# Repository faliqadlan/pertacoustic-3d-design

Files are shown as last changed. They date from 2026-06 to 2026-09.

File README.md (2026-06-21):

# Pertacoustic Study: Spectral Noise Logging (SNL) Well Diagnostics

This repository contains the software configuration, design targets, and research artifacts for the **Pertacoustic Study** (Studi Pertacoustic untuk Mengatasi Permasalahan Air), a joint research and development project conducted in collaboration with **Laboratorium Geofisika FMIPA Universitas Gadjah Mada (UGM)** and **PT Pertamina Hulu Energi (PHE) Upstream Innovation**.

---

## Project Overview
The project focuses on developing hardware and software components for high-sensitivity, high-resolution **Spectral Noise Logging (SNL)** using downhole hydrophones. SNL is a passive acoustic diagnostic methodology used to detect and characterize:
- Tubing and casing leaks
- Behind-casing fluid migration (cement channeling)
- Reservoir fluid inflow and production profiles
- Cross-flow behind single or multiple concentric barriers

---

## Repository Structure
*   `2604.05547v1.pdf`: Research reference on closed-loop CAD-CAE agentic optimization (COSMO-Agent).
*   `260619_PERTACOUSTIC_BIWEEKLY_2.pdf`: Biweekly progress report II (UGM & Pertamina Hulu Energi).
*   `FIND-specification-flyer.pdf`: North Side Tools FIND (Flow Identifying Noise Detector) specifications.
*   `commercial_snl_tools.md`: Comparative study of major commercial downhole SNL tools (GOWell SNT, TGT Chorus, Schlumberger HFND, etc.).
*   `pertacoustic_tool_targets.md`: Wellbore environmental operating specifications tailored for PHE oil wells.
*   `downhole_tool_components.md`: Auxiliary components list, specifications, pricing, and system-level budgets.
*   `SESSION_LOG.md`: Session logs and progress summary.

---

## Technical Specifications Target (PHE Oil Wells)
- **Temperature Limits**: 150°C BHT max (supporting standard reservoirs and steamflood EOR like Duri field).
- **Hydrostatic Pressure**: 10,000 PSI max (engineered for standard development and exploratory oil wells).
- **Depth Limit**: 3,500 meters.
- **Fluid Compatibility**: Heavy crude oil (17° to 22° API).
- **Sour Service Certification**: 6% to 25% H2S, 10% CO2.

---

## Persistent Session Memory (Antigravity 2.0)

To prevent the Antigravity agent from starting discussions from scratch when you open a new conversation or switch machines, follow these memory-preservation guidelines:

### 1. Maintain `SESSION_LOG.md` (Episodic Memory)
*   **How it works**: Antigravity automatically scans and reads all markdown files in the workspace at initialization.
*   **Action**: Ensure that `SESSION_LOG.md` is updated at the end of each session. The agent will read this log in any new conversation to immediately recall previous discussions, decisions, and files without requiring you to re-explain.

### 2. Define Workspace Rules in `.agents/AGENTS.md` (Procedural Memory)
*   **How it works**: Workspace-scoped agent rules are automatically loaded into the agent's system instructions at startup.
*   **Action**: Add custom rules in `.agents/AGENTS.md` to define design decisions (e.g., *"We are building Option C (Hybrid Premium AS-1 + Titanium Casing) at ~$4,353 USD"*). This locks the current architecture choice into the agent's behavior.

### 3. Synchronize via GitHub (Cross-Laptop Sync)
*   **How it works**: Git acts as the shared long-term memory across different computers.
*   **Action**: 
    1.  At the end of a session, run: `git add . && git commit -m "sync memory" && git push`
    2.  When opening a new conversation or using a different laptop, run: `git pull` before launching the agent.
    3.  This restores the exact workspace files, agent rules, custom skills, and logs.

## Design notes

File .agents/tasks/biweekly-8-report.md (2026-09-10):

---
title: PertAcoustic Biweekly 8 Reporting Contract
document_id: AGENT-TASK-BIWEEKLY-8-REPORT
version: 1.1
status: Validated/Published
language: en-US
last_updated: 2026-09-10
scope:
  - PertAcoustic Biweekly 8 report generation
  - accepted compact-casing evidence synthesis
  - reporting traceability and evidence labeling
  - native Google Docs human-facing deliverable
  - reporting-only repository source artifact maintenance
authority_note: This task authorizes a reporting and traceability deliverable only. It does not redefine, broaden, amend, supersede, or retroactively reinterpret the compact-casing engineering contract or accepted engineering evidence.
---

# Executable Task

This file defines the bounded delivery contract for remediating the PertAcoustic Biweekly 8 report in a later Executor run.

The report is a communication and traceability artifact derived from accepted repository evidence. The repository Markdown remains the traceability/source artifact; the primary human-facing deliverable is a native Google Doc. Neither artifact is the engineering source of truth.

## Task identity

**Task title:**  
PertAcoustic Biweekly 8 Evidence-Based Progress Report

**Task path:**  
`.agents/tasks/biweekly-8-report.md`

**Task contract state:**  
Validated/Published

The task file is the executable delivery contract.

Execution and review lifecycle states such as `In Execution`, `Review Required`, `Remediation Required`, and `Accepted` SHOULD normally be tracked by orchestration, review records, repository metadata, or another mechanism that preserves the exact governing task revision.

A lifecycle-status update MUST NOT silently replace the immutable task revision that governed an execution attempt.

When remediation materially changes this executable contract, edit this same stable task path, return it to Draft as needed, and republish it as a new immutable governing task revision before renewed execution.

**Delivery objective / Work Package / MVP:**  
PertAcoustic reporting work package: Biweekly 8 accepted-evidence report

**Owner / designated planning authority:**  
PertAcoustic Research Collaboration / Planner-Reviewer reporting authority

## Delivery context

Biweekly 8 must summarize accepted PertAcoustic engineering progress at the current reporting cutoff:

```text
main@667ccd59cf6657a75dfe3cc2b4c67488737ef028
```

The principal engineering work being reported is governed by:

```text
.agents/tasks/compact-downhole-casing-redesign.md @ ad24d9146815f88368d8f6b1d635831d57aed13d
```

That engineering task recorded implementation baseline:

```text
b33e1622b04ec5e723c634573dbfa93aaa065576
```

The current report implementation requiring remediation is:

```text
29a602029cf55a0b036887d776440447325bd864
```

That implementation created the repository source artifact:

```text
results/biweekly-8/biweekly-8.md
```

The future remediated report must explain, with traceable evidence:

1. what the engineering state was before the compact-casing redesign;
2. what engineering work was completed;
3. what evidence was produced;
4. what changed from the previous accepted baseline;
5. what the current preliminary engineering configuration is;
6. which results are VERIFIED, DERIVED SCREENING, ASSUMED SCREENING, HISTORICAL, PROVISIONAL, or UNRESOLVED;
7. what remains unresolved; and
8. what engineering work should happen next.

The report must be suitable for PertAcoustic project members, academic supervisors, engineering collaborators, and project decision-makers. Technical clarity and traceability are more important than presentation decoration.

The primary human-facing deliverable MUST be a native Google Doc titled:

```text
3d-design-biweekly-8
```

The Google Doc MUST be created directly in the specified PertAcoustic Google Drive folder:

```text
https://drive.google.com/drive/folders/14V4rGX0lwHmwCNOGn8BQYE-0R6DH-Fy9
```

The existing Biweekly 5 Google Doc is a formatting and editorial template only:

```text
https://docs.google.com/document/d/1hAxKtHvkiHflduqY9msiPGFDHWHsi38WFNxwXvtDBFk/edit
```

The Biweekly 5 Google Doc and repository Biweekly 5 artifacts are historical engineering evidence. They MUST NOT be cited or treated as current engineering authority. If the Google Doc is copied as a native formatting template, copied historical content MUST be replaced or clearly relabeled as historical. Biweekly 5 may constrain only the visual/editorial form of the Biweekly 8 Google Doc.

The repository/project evidence inspected for task publication does not establish a reliable Biweekly 6 / Biweekly 7 reporting-period chain. The future report MUST NOT invent reporting-period dates or a Biweekly 7 repository artifact. If authoritative dates remain unavailable, record the dates as unresolved and make the evidence cutoff explicit.

## Baseline and task revision

**Implementation baseline:**  
`29a602029cf55a0b036887d776440447325bd864`

**Task revision:**  
Resolved by the immutable Git commit that publishes this task file. The preferred identity is:

```text
.agents/tasks/biweekly-8-report.md @ <full Git commit SHA containing this task content>
```

The task body does not need to embed the commit SHA that contains itself. The Executor MUST use the exact immutable task revision supplied by the Planner/Reviewer handoff or Git history before starting report generation.

The implementation baseline and governing task revision are separate references. The implementation baseline is the current report implementation requiring remediation. The accepted engineering reporting cutoff remains `667ccd59cf6657a75dfe3cc2b4c67488737ef028`.

Do not change the implementation baseline silently during execution. If `origin/main` or the accepted reporting cutoff has moved, stop and return to Planner/Reviewer for reporting-cutoff review before remediating Biweekly 8.

## Objective

Remediate the existing coherent, evidence-based PertAcoustic Biweekly 8 report from accepted repository evidence by keeping `results/biweekly-8/biweekly-8.md` as the repository traceability/source artifact and creating a native Google Docs primary human-facing deliverable in the specified PertAcoustic Drive folder.

The report MUST synthesize accepted engineering evidence without making new engineering design decisions, changing source-of-truth engineering artifacts, or overstating preliminary screening as qualification.

## Authoritative inputs

### Governing authority

- Repository delivery governance:
  - `AGENTS.md`
  - `.agents/AGENTS.md`
  - `.agents/software-workflow.md`
  - `.agents/context/project.md`
- This reporting task:
  - `.agents/tasks/biweekly-8-report.md @ <published immutable task revision>`
- Governing compact-casing engineering task:
  - `.agents/tasks/compact-downhole-casing-redesign.md @ ad24d9146815f88368d8f6b1d635831d57aed13d`
- Accepted reporting cutoff:
  - `main@667ccd59cf6657a75dfe3cc2b4c67488737ef028`
- Previous governing reporting task revision:
  - `.agents/tasks/biweekly-8-report.md @ c1d8d7c00d6fe3b3055bdabebb604f4e49bb86cb`
- Current report implementation requiring remediation:
  - `29a602029cf55a0b036887d776440447325bd864`
- Biweekly 8 Google Doc target:
  - Title: `3d-design-biweekly-8`
  - Folder: `https://drive.google.com/drive/folders/14V4rGX0lwHmwCNOGn8BQYE-0R6DH-Fy9`
- Formatting/editorial template only:
  - Biweekly 5 Google Doc: `https://docs.google.com/document/d/1hAxKtHvkiHflduqY9msiPGFDHWHsi38WFNxwXvtDBFk/edit`

### Primary repository evidence

Prioritize evidence in this order:

1. Current accepted repository implementation and generated results at the reporting cutoff.
2. The exact governing engineering task revision.
3. Actual executed test, simulation, CAD, and generated evidence.
4. Formal project decisions represented in repository authority/context.
5. Manufacturer, supplier, standard, or paper evidence already properly traced by the accepted engineering work.
6. Engineering measurements.
7. Historical Biweekly reports.
8. Informal discussion or context only when appropriately labeled.

Important evidence surfaces include:

- `results/compact-casing/compact_casing_redesign_report.md`
- `results/compact-casing/compact_casing_id_od_envelope.csv`
- `results/compact-casing/compact_casing_trade_study.csv`
- `results/compact-casing/figures/`
- `cosmo/compact_casing.py`
- `tests/test_compact_casing.py`
- `results/biweekly-5/biweekly-5.md`
- `results/biweekly-5/figures/`
- `results/biweekly-5/cad/`
- `results/biweekly-5/summary.json`
- `results/biweekly-5/thermal_results.csv`
- `results/biweekly-5/structural_fea_results.csv`
- `results/biweekly-5/mesh_convergence.csv`
- `results/biweekly-5/input_spec.json`
- `.agents/context/biweekly-5/`
- `results/biweekly-8/biweekly-8.md`

Historical Biweekly 5 artifacts must remain unchanged.

The Biweekly 5 Google Doc and repository Biweekly 5 artifacts are HISTORICAL engineering evidence. They may be used for formatting/editorial style and previous-baseline comparison only. They MUST NOT be treated as current engineering authority.

### Requirement traceability

- `REQ-RPT8-001` (Evidence-bound report) -> This task, repository governance, and reporting cutoff: Biweekly 8 must synthesize accepted evidence without inventing unsupported progress.
- `REQ-RPT8-002` (Current configuration reconciliation) -> Accepted compact-casing evidence: the report must reconcile preliminary dimensions, materials, architecture, and status labels against repository evidence before publication.
- `REQ-RPT8-003` (Strict thermal semantics) -> Accepted compact-casing evidence and task constraints: shell-coupled lower-bound thermal results must not be relabeled as electronics temperature.
- `REQ-RPT8-004` (Strict structural semantics) -> Accepted compact-casing evidence and unresolved pressure authority: structural screening must remain conditional and must not be presented as pressure qualification.
- `REQ-RPT8-005` (Historical preservation) -> Repository context and historical reporting evidence: Biweekly 5 artifacts must remain unchanged and historical facts must be labeled historical.
- `REQ-RPT8-006` (Traceable reporting package) -> Repository reporting convention and human requirement change: `results/biweekly-8/biweekly-8.md` remains the repository traceability/source artifact, while the native Google Doc is the primary human-facing deliverable.
- `REQ-RPT8-007` (Native Google Docs deliverable) -> Human requirement change: Biweekly 8 must be created as a native Google Doc titled `3d-design-biweekly-8` directly in the specified PertAcoustic Google Drive folder.
- `REQ-RPT8-008` (Biweekly 5 style template boundary) -> Human requirement change: the Biweekly 8 Google Doc must closely match the visual/editorial structure of the Biweekly 5 Google Doc while treating Biweekly 5 only as historical evidence and formatting/editorial template material.

Do not use existing implementation as retroactive justification for missing authority.

## Scope

### In scope

- Synthesize accepted engineering evidence into a Biweekly 8 report.
- Preserve and, if needed, update the repository source artifact under:

```text
results/biweekly-8/
  biweekly-8.md
  figures/        if justified
  supporting generated evidence only when required
```

- Create a native Google Doc titled `3d-design-biweekly-8` directly in:

```text
https://drive.google.com/drive/folders/14V4rGX0lwHmwCNOGn8BQYE-0R6DH-Fy9
```

- Use the Biweekly 5 Google Doc only as a formatting/editorial template.
- Write the primary Google Doc in Indonesian.
- Match the Biweekly 5 Google Doc style closely enough to preserve report readability and audience expectations, including report-style title, period/date/status block, concise disclaimer, numbered engineering sections, explanatory prose, native Google Docs tables, inline engineering figures, figure captions, references section, typography, heading hierarchy, and page layout.
- Select relevant accepted engineering figures when useful.
- Create reporting-only explanatory tables or figures when justified by traceability and generated from accepted evidence.
- Create evidence and traceability tables where useful.
- Record the final Google Doc identity, URL, and folder placement in the Executor's evidence and, if appropriate, in `results/biweekly-8/biweekly-8.md` without turning the Google Doc into engineering authority.
- Document unresolved engineering gaps.
- Document next engineering work.
- Verify report consistency, dimensions, units, claims, evidence links, and figure captions.

### Out of scope

- Creating `results/biweekly-8/` or `biweekly-8.md` before this task is executed in a future reporting slice.
- Changing the current engineering design.
- Choosing a different OD merely for reporting.
- Changing casing wall thickness.
- Changing material selection.
- Introducing a new carrier material.
- Modifying thermal physics.
- Changing structural models.
- Changing pressure assumptions.
- Changing HTI geometry.
- Inventing actual electronics dimensions.
- Inventing measured power dissipation.
- Fabricating prototype results.
- Claiming field qualification, pressure qualification, manufacturing readiness, or downhole qualification.
- Modifying, renaming, overwriting, or regenerating historical Biweekly 5 evidence.
- Modifying the Biweekly 5 Google Doc.
- Modifying `cosmo/compact_casing.py`, compact-casing result artifacts, tests, or other engineering source-of-truth data to make the report easier to write.
- Creating a PDF, slide deck, or alternative publication artifact unless separately authorized.
- Treating the Google Doc, Biweekly 5 Google Doc, or the Markdown report as engineering source-of-truth authority.

### Preserved behavior

- Historical reporting directories remain unchanged, especially `results/biweekly-5/`.
- The Biweekly 5 Google Doc remains unchanged.
- Compact-casing engineering source and accepted generated evidence remain unchanged.
- Repository governance and task contract semantics remain unchanged.
- `results/biweekly-8/biweekly-8.md` remains the repository traceability/source artifact.
- Preliminary engineering results remain clearly preliminary.
- Assumptions, historical values, and unresolved items remain visible.

If report preparation exposes a genuine engineering inconsistency, record it as a reporting blocker or finding rather than silently fixing engineering source-of-truth data inside this reporting task.

## Current engineering baseline to preserve

Before publication, the future report MUST reconcile these current accepted preliminary values against repository evidence:

- Pressure shell: Inconel 718.
- Preferred casing OD: 44.45 mm / 1.75 in.
- Maximum screening OD: 57.15 mm / 2.25 in.
- Preliminary wall: 3.50 mm.
- Resulting shell bore: 37.45 mm.
- Project internal-diameter direction: ID > 30 mm.
- Critical interpretation: 30 mm is a lower bound, not the target internal diameter.
- Current electronics screening requirement: approximately 34.93 mm circular packaging envelope.
- Current preliminary diametral packaging margin: approximately 2.52 mm.
- Current architecture:
  - Inconel 718 metallic pressure shell.
  - Discrete/conformal polymer electronics carrier.
  - Electronics inside the carrier.
  - No aerogel baseline.
- Carrier hierarchy:
  - PA66-GF30: PRIMARY NYLON PROTOTYPE / VALIDATION CANDIDATE.
  - PEEK: ENGINEERING BENCHMARK / REFERENCE.
  - PPA: HIGHER-PERFORMANCE POLYAMIDE ALTERNATIVE / SECONDARY VALIDATION CANDIDATE.

The report MUST NOT call:

- PA66 downhole-qualified;
- the polymer carrier a pressure boundary;
- the current casing pressure-qualified;
- the current design manufacturing-ready;
- the design field-qualified.

## Reporting content requirements

The Google Doc MUST be written in Indonesian and use explanatory engineering prose rather than audit-oriented prose. It MUST include, at minimum:

1. Ringkasan Kemajuan.
2. Periode, status, dan batas bukti.
3. Pekerjaan yang selesai pada periode pelaporan.
4. Konfigurasi teknik saat ini.
5. Analisis teknik, covering these topics where supported:
   - mechanical packaging;
   - ID/OD envelope;
   - material/carrier selection;
   - structural screening;
   - thermal screening;
   - electronics packaging;
   - HTI/acoustic interface.
6. Perbandingan dengan baseline sebelumnya, explicitly explaining the transition from the earlier large casing / aerogel-oriented concept toward the compact architecture.
7. Verifikasi dan bukti, including the exact repository revision and generated evidence used.
8. Keputusan teknik saat ini.
9. Hal yang belum terselesaikan / risiko.
10. Pekerjaan teknik berikutnya.
11. Referensi.
12. Evidence / traceability table where useful.

The Google Doc MUST closely match the Biweekly 5 document's visual and editorial pattern:

- Indonesian language.
- Report-style title.
- Period/date/status block near the top.
- Concise disclaimer that the report is not a manufacturing drawing, pressure qualification, field qualification, or new engineering source of truth.
- Numbered engineering sections.
- Explanatory prose rather than audit-oriented prose.
- Native Google Docs tables, not pasted Markdown table text or screenshots of tables.
- Engineering figures embedded inline from accepted evidence when useful.
- Figure captions placed next to the corresponding figures.
- References section.
- Approximately the same typography, heading hierarchy, page layout, and overall readability as the Biweekly 5 Google Doc.

`results/biweekly-8/biweekly-8.md` MUST remain an English or repository-conventional traceability/source artifact unless the Executor has a clearly bounded reason to translate it. The Google Doc is the Indonesian human-facing deliverable.

Assess and include these items only when supported by reporting-cutoff evidence:

- compact-casing redesign;
- 1.75 in / 44.45 mm OD recommendation;
- 3.50 mm preliminary Inconel wall;
- 37.45 mm bore;
- 30 mm ID as lower bound rather than target;
- current approximately 34.93 mm electronics screening requirement;
- approximately 2.52 mm packaging margin;
- removal of aerogel from the current baseline;
- PA66-GF30 first-prototype direction;
- PEEK benchmark/reference role;
- PPA secondary-candidate role;
- structural-screening results;
- unresolved authoritative pressure;
- current shell thermal-screening results;
- limitations of the present thermal model;
- actual electronics dimensional measurement requirement;
- actual electronics power requirement;
- planned PA66 physical validation;
- next thermal-development step;
- unresolved HTI supplier-controlled thread/seal/interface geometry.

Do not add unsupported engineering progress merely to make Biweekly 8 appear more substantial.

## Thermal semantics

The report MUST use strict thermal wording.

The current 70 C model may support discussion of:

- shell response;
- inner-shell temperature;
- shell-coupled lower-bound behavior;
- present thermal-screening limitations.

It MUST NOT be presented as directly establishing:

- PCB temperature;
- electronics cavity temperature;
- STM32 junction temperature;
- PCM1808 junction temperature;
- complete electronics temperature;
- electronics qualification.

The current result is:

```text
IDEAL SHELL-COUPLED LOWER-BOUND TEMPERATURE (INNER SHELL SURFACE)
```

Do not relabel it as "electronics temperature".

The report MUST explicitly state that stronger thermal work requires:

```text
environment
-> Inconel shell
-> shell/carrier contact
-> polymer carrier
-> PCB/contact
-> electronics heat sources
```

with measured or justified thermal resistances and actual electronics power.

## Structural semantics

Structural conclusions MUST remain:

```text
CONDITIONAL - DESIGN PRESSURE UNRESOLVED
```

Current pressure scenarios may be reported only according to their evidence status:

- `~10 MPa`: screening context.
- `20 MPa`: sensitivity case.
- `68.95 MPa / 10,000 psi`: historical comparison where applicable.

None of these establishes authoritative field design pressure.

A calculated screening factor of safety MUST NOT be presented as pressure qualification.

## Dependencies and assumptions

### Dependencies

- Local repository state at `29a602029cf55a0b036887d776440447325bd864`.
- Published reporting task revision for this task.
- Accepted compact-casing engineering evidence at the reporting cutoff.
- Historical Biweekly 5 artifacts for comparison and provenance.
- Read access to the Biweekly 5 Google Doc for formatting/editorial template inspection.
- Google Drive connector/API access sufficient to create or update one native Google Doc in the specified target folder.

### Approved assumptions

- `results/biweekly-8/biweekly-8.md` is the repository traceability/source artifact.
- The native Google Doc titled `3d-design-biweekly-8` is the primary human-facing deliverable.
- Figures are optional and must be justified by evidence and provenance.
- Reporting-period dates are unresolved unless authoritative repository/project evidence establishes them during execution.
- The Biweekly 5 Google Doc provides visual/editorial structure only; it is not current engineering authority.

### Remaining approval requirements

- Planner/Reviewer must inspect this exact task revision before report implementation is authorized.
- The future Executor must return the generated Biweekly 8 artifacts for review and must not self-accept the report.
- Authorization is granted only for creation or update of the Biweekly 8 Google Doc titled `3d-design-biweekly-8` in the specified PertAcoustic folder.
- Any request to modify Biweekly 5, publish outside the specified folder, push, open a PR, release, deploy, or perform other external publication requires separate authorization.

## Required capabilities

- Repository read and write.
- Git state inspection.
- Local shell command execution for non-destructive verification.
- Markdown authoring.
- Google Drive connector/API access for native Google Doc creation/update in the specified folder.
- Google Docs editing capability for native text, headings, page layout, tables, inline figures, captions, and references.
- Ability to inspect CSV, Markdown, Python, generated figures, and repository history.
- Existing project test execution when proportionate to verifying preservation.

No new PDF generator, slide toolchain, or local dependency is required. The Google Drive/Docs capability is required only for the authorized native Google Doc deliverable.

## Execution constraints

### Constraints

- Use the reporting cutoff exactly; do not silently move to a newer revision.
- Start remediation from the current report implementation baseline `29a602029cf55a0b036887d776440447325bd864` unless Planner/Reviewer supplies a newer remediation baseline.
- Do not generate engineering evidence or rerun simulations unless a specific report consistency check requires non-destructive verification and the generated output remains within this reporting task's scope.
- Do not duplicate compact-casing numerical artifacts merely to make `results/biweekly-8/` self-contained when traceable references are sufficient.
- If figures are reused from accepted current engineering evidence, preserve provenance.
- If a figure must be regenerated, regenerate from the canonical generator/source rather than manually modifying an image.
- Use established repository reporting conventions; do not create a new reporting framework.
- Use the Biweekly 5 Google Doc only to copy or reproduce visual/editorial structure for the Biweekly 8 Google Doc.
- If the Executor copies the Biweekly 5 Google Doc as a template, the copied document MUST be created as the new Biweekly 8 document titled `3d-design-biweekly-8` in the specified target folder, and all copied historical content MUST be replaced or relabeled so it cannot be mistaken for current Biweekly 8 engineering evidence.
- Do not mutate the Biweekly 5 Google Doc.
- Keep claims tied to evidence status labels.
- Use concise technical language suitable for the stated audiences.

## Acceptance criteria

- [ ] `results/biweekly-8/biweekly-8.md` exists and remains the repository traceability/source artifact for Biweekly 8.
- [ ] A native Google Doc titled `3d-design-biweekly-8` exists directly in the specified PertAcoustic Google Drive folder.
- [ ] The Google Doc is the primary human-facing deliverable and is written in Indonesian.
- [ ] The Google Doc closely follows the Biweekly 5 Google Doc's visual/editorial style: report-style title, period/date/status block, concise disclaimer, numbered engineering sections, explanatory prose, native Google Docs tables, inline engineering figures, figure captions, references section, typography, heading hierarchy, page layout, and readability.
- [ ] The Biweekly 5 Google Doc is not modified.
- [ ] The report records the exact repository revision/evidence cutoff: `667ccd59cf6657a75dfe3cc2b4c67488737ef028`.
- [ ] The report identifies the governing compact-casing task revision: `ad24d9146815f88368d8f6b1d635831d57aed13d`.
- [ ] The report identifies the governing reporting task revision used for remediation.
- [ ] Reporting-period dates are either supported by authoritative evidence or explicitly recorded as unresolved.
- [ ] Numbers match accepted engineering evidence; OD, ID, wall, bore, and packaging-margin dimensions are internally consistent and units are correct.
- [ ] Figures correspond to the described quantity, preserve provenance, and captions do not overclaim.
- [ ] Google Doc tables are native Google Docs tables, not pasted Markdown table text or screenshots.
- [ ] Engineering figures are embedded inline in the Google Doc when used, with captions and provenance.
- [ ] Historical values are clearly historical.
- [ ] Preliminary results are clearly preliminary.
- [ ] Assumptions remain labeled.
- [ ] Unresolved issues remain visible.
- [ ] References support their associated statements.
- [ ] Structural screening is not presented as qualification.
- [ ] Shell temperature is not presented as electronics temperature.
- [ ] The report preserves historical Biweekly artifacts, especially `results/biweekly-5/`.
- [ ] The report does not modify compact-casing engineering source/results or create new engineering decisions.

## Verification requirements

### Required checks

- Verify Git state and confirm the implementation baseline/reporting cutoff used for report remediation.
- Inspect `git diff --name-only` or equivalent and confirm changes are limited to authorized Biweekly 8 reporting artifacts.
- Check that `results/biweekly-5/` is unmodified.
- Check that the Biweekly 5 Google Doc was not modified.
- Check that compact-casing engineering source/results are unmodified unless Planner/Reviewer explicitly authorized a reporting-only exception.
- Review `biweekly-8.md` against accepted evidence for dimension, unit, classification, and semantic consistency.
- Verify the native Google Doc title, folder placement, language, document structure, native tables, inline figures, captions, references, and link/identity.
- Verify the Google Doc does not treat the Biweekly 5 template as current engineering authority.
- Run the smallest relevant existing test or repository check needed to demonstrate preservation if any executable source or generated engineering artifact is touched. If only Markdown/reporting artifacts and the authorized Google Doc are changed, record that no code tests were required and explain why.

### Required evidence

The Executor MUST report:

- exact implementation revision or precise working-tree state;
- task revision used;
- reporting cutoff used;
- current report implementation baseline used;
- files changed;
- Google Doc title, URL/document ID, and target folder confirmation;
- Google Drive mutations performed;
- commands/checks actually executed and observed results;
- evidence sources used;
- tests not run and rationale;
- known verification gaps;
- unresolved reporting or engineering items;
- confirmation that engineering implementation was not changed;
- confirmation that historical Biweekly artifacts were not modified.

Do not represent unobserved, skipped, or local-only checks as broader evidence than they actually provide.

## Stop conditions

The Executor MUST stop report implementation and return the issue to planning when any of the following materially affects the task:

- `origin/main` or the accepted reporting cutoff no longer matches `667ccd59cf6657a75dfe3cc2b4c67488737ef028` and no reviewed new cutoff has been supplied.
- The current report implementation baseline `29a602029cf55a0b036887d776440447325bd864` cannot be resolved and no reviewed replacement remediation baseline has been supplied.
- The governing compact-casing task revision cannot be resolved.
- Accepted compact-casing evidence does not support the current preliminary values listed in this task.
- Report generation requires changing engineering authority, design source, simulation source, or accepted engineering results.
- The report would need to invent a product or engineering decision.
- Historical Biweekly evidence would need destructive modification.
- The Biweekly 5 Google Doc would need to be modified.
- Google Drive connector/API access is unavailable or cannot create/update the Biweekly 8 Google Doc directly in the specified target folder.
- The target PertAcoustic Google Drive folder cannot be resolved or is not writable.
- The Biweekly 5 Google Doc cannot be inspected sufficiently to reproduce its visual/editorial structure.
- Reporting-period dates cannot be established and a stakeholder requires exact dates rather than unresolved chronology.
- An externally visible action outside the single authorized Biweekly 8 Google Doc creation/update becomes necessary.

Do not stop merely because reporting-period dates are unresolved, some report data are intentionally unresolved, or the final report requires review after generation. Represent those uncertainties accurately.

## Side-effect authorization

Implementation authorization is strictly bounded to the task's defined reporting scope.

Unless explicitly authorized by this task, applicable repository policy, or designated authority, the task does NOT authorize:

- engineering source changes;
- compact-casing result modification;
- historical Biweekly 5 modification;
- Biweekly 5 Google Doc modification;
- dependency installation or replacement;
- Git push;
- remote branch creation;
- pull request creation;
- deployment;
- external publication;
- release;
- destructive cleanup;
- force-push or history rewrite;
- external-system mutation.

### Explicitly authorized side effects

- Create `results/biweekly-8/`.
- Create `results/biweekly-8/biweekly-8.md`.
- Update `results/biweekly-8/biweekly-8.md` only as needed to preserve source/traceability consistency with the remediated Google Doc.
- Create `results/biweekly-8/figures/` only if justified by the report and provenance is preserved.
- Create minimal supporting generated reporting evidence under `results/biweekly-8/` only when required for traceability.
- Use the Google Drive connector/API to create or update only the Biweekly 8 native Google Doc titled `3d-design-biweekly-8` directly in the specified PertAcoustic folder.
- Use the Google Drive connector/API to copy/create the Biweekly 8 Google Doc from the Biweekly 5 Google Doc as a formatting/editorial template only, if that is the most reliable way to preserve native style.
- Use the Google Drive connector/API to write Biweekly 8 document content, create native Google Docs tables, insert accepted engineering figures inline, add figure captions, and record references in the Biweekly 8 Google Doc.
- Run non-destructive local verification.

Git commit authorization is not implied for the future reporting Executor unless separately supplied by the handoff for that execution slice.

The explicit Google Drive authorization above applies only to creating or updating the Biweekly 8 Google Doc in the specified folder. It does not authorize modification of the Biweekly 5 Google Doc, creation of additional Drive deliverables, link-sharing changes, publication outside the target folder, or any unrelated external-system mutation.

## Expected terminal outcome

The Executor's implementation phase SHOULD end in **Review Required**:

- `results/biweekly-8/biweekly-8.md` exists.
- Native Google Doc `3d-design-biweekly-8` exists in the specified PertAcoustic Google Drive folder.
- Any justified supporting reporting artifacts exist under `results/biweekly-8/`.
- Verification evidence is truthfully reported.
- Engineering implementation changed: NO.
- Historical Biweekly artifacts modified: NO.
- Biweekly 5 Google Doc modified: NO.
- Biweekly 8 report source artifact generated/maintained: YES.
- Biweekly 8 Google Doc created/updated: YES.

The Executor does not self-declare final acceptance.

## Review and remediation handling

The Reviewer evaluates report artifacts against the exact governing task revision, reporting cutoff, accepted engineering evidence, and observed verification evidence.

If review identifies bounded corrections within the same reporting objective, update and republish this same task file only if the executable contract itself must change. Ordinary report corrections should remain implementation remediation under this task.

Materially new engineering objectives, new design decisions, new simulations, new authority needs, or scope expansion MUST return to Delivery Planning and become separate task work.

## Remediation

**Review basis:**
`.agents/tasks/biweekly-8-report.md @ c1d8d7c00d6fe3b3055bdabebb604f4e49bb86cb`

**Current report implementation:**
`29a602029cf55a0b036887d776440447325bd864`

### Required corrections

- Preserve `results/biweekly-8/biweekly-8.md` as the repository traceability/source artifact.
- Create the primary human-facing Biweekly 8 deliverable as a native Google Doc titled `3d-design-biweekly-8` directly in the specified PertAcoustic Google Drive folder.
- Use the Biweekly 5 Google Doc only as formatting/editorial template material.
- Write the Google Doc in Indonesian with a report-style title, period/date/status block, concise disclaimer, numbered engineering sections, explanatory prose, native Google Docs tables, inline accepted engineering figures, figure captions, references, and matching visual hierarchy/readability.
- Preserve all strict engineering semantics in this task, including dimensions, no-aerogel architecture, material hierarchy, unresolved pressure status, and thermal lower-bound labeling.
- Do not modify Biweekly 5 repository artifacts or the Biweekly 5 Google Doc.

### Additional verification

- Verify the Google Doc title, native format, target folder placement, Indonesian language, section structure, native tables, figure placement, captions, and references.
- Verify Biweekly 5 repository artifacts and the Biweekly 5 Google Doc remain unmodified.
- Verify the Executor's reported Google Drive mutations are limited to the authorized Biweekly 8 document in the specified folder.

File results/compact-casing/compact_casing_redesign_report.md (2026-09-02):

# PertAcoustic Compact Downhole Casing Redesign Report
## Simplified Architecture & Polymer Carrier Material Trade Study (70 °C / 2-Hour Envelope)

**Document ID:** PERT-REP-COMPACT-002  
**Design Direction:** Simplified 70 °C Operational Environment (Inconel 718 + Conformal Polymer Carrier + No Aerogel)  
**Status:** Engineering Screening Complete — Review Required  
**Governing Task:** `.agents/tasks/compact-downhole-casing-redesign.md`

---

## 1. Executive Summary & Direct Engineering Answers

This engineering screening trade study evaluates whether a PA66-GF30 electronics carrier can be practically used inside the Inconel 718 pressure shell for the 70 °C / 2-hour target, subject to physical validation of wet dimensional behaviour, packaging, and the unresolved internal thermal path. It does not establish downhole material qualification.

The accepted mechanical architecture remains:
- **44.45 mm / 1.75 in OD**
- **Inconel 718 metallic pressure shell**
- **3.50 mm preliminary packaging-favorable screening wall**
- **37.45 mm shell bore**
- **Conformal polymer electronics carrier with integrated card guides**
- **No aerogel insulation**
- **Total modeled tool length: 656.9 mm** (CAD Bounding Span: **656.9 mm**)

### Direct Answers to Required Engineering Questions:

## ID/OD Envelope and Prototype Geometry Recommendation

- **Recommendation basis:** **PRELIMINARY ENGINEERING SCREENING**
- **Structural authority status:** **STRUCTURAL ACCEPTANCE CONDITIONAL ON AUTHORITATIVE DESIGN PRESSURE** (evaluated under ~10 MPa screening context; authoritative casing design pressure remains unresolved).
- **Minimum ID requirement / project floor:** ID > **30.0 mm**. This is a lower bound, not a design target.
- **Preferred OD / maximum OD:** **44.45 mm / 1.750 in** / **57.15 mm / 2.250 in**.
- **Current electronics-required diameter:** **34.93 mm**, derived from the PCM1808 transverse envelope plus 1.0 mm per side.
- **Selected preliminary geometry:** **44.45 mm OD / 37.45 mm ID / 3.50 mm wall**; packaging margin **2.52 mm** (derived via explicit multi-gate selection).
- **Wall decision:** 3.5 mm remains the packaging-favorable screening configuration; 4.0 mm remains the higher-collapse-margin sensitivity.
- **30 mm is not the design target:** it can satisfy the project floor statement while failing the current PCM1808 breakout packaging requirement.
- **Further OD reduction requires:** actual board, header, connector, wiring, bend-radius, carrier, and manufacturing-clearance measurements.
- **Structural screening trends:** As shown in the matrix below, increasing OD at fixed wall thickness reduces the elastic buckling margin (e.g. 10 MPa buckling FoS drops from 11.33 at 44.45 mm OD to 5.33 at 57.15 mm OD for 3.5 mm wall). Under 10,000 psi (68.95 MPa) historical comparison, 3.5 mm wall has FoS < 2.0 across all ODs, whereas 4.0 mm wall maintains FoS >= 2.0 only at 44.45 mm OD. Passing 10 MPa screening does NOT imply pressure qualification.

| OD (mm) | OD (in) | Wall (mm) | ID (mm) | Pkg Margin (mm) | 10 MPa Yield FoS | 10 MPa Buckle FoS | 20 MPa Buckle FoS | 10k psi Buckle FoS | 10 MPa Screening | Structural Authority | Recommendation |
|---:|---:|---:|---:|---:|---:|---:|---:|---:|---|---|---|
| 44.450 | 1.750 | 3.50 | 37.45 | 2.52 | 16.75 | 11.33 | 5.67 | 1.64 | PASS @ 10 MPa SCREENING | CONDITIONAL — DESIGN PRESSURE UNRESOLVED | RECOMMENDED PRELIMINARY CONFIGURATION |
| 44.450 | 1.750 | 4.00 | 36.45 | 1.52 | 18.91 | 16.92 | 8.46 | 2.45 | PASS @ 10 MPa SCREENING | CONDITIONAL — DESIGN PRESSURE UNRESOLVED | VIABLE SCREENING ALTERNATIVE |
| 47.625 | 1.875 | 3.50 | 40.62 | 5.70 | 15.72 | 9.21 | 4.61 | 1.34 | PASS @ 10 MPa SCREENING | CONDITIONAL — DESIGN PRESSURE UNRESOLVED | VIABLE SCREENING ALTERNATIVE |
| 47.625 | 1.875 | 4.00 | 39.62 | 4.70 | 17.77 | 13.75 | 6.88 | 1.99 | PASS @ 10 MPa SCREENING | CONDITIONAL — DESIGN PRESSURE UNRESOLVED | VIABLE SCREENING ALTERNATIVE |
| 50.800 | 2.000 | 3.50 | 43.80 | 8.87 | 14.81 | 7.59 | 3.80 | 1.10 | PASS @ 10 MPa SCREENING | CONDITIONAL — DESIGN PRESSURE UNRESOLVED | VIABLE SCREENING ALTERNATIVE |
| 50.800 | 2.000 | 4.00 | 42.80 | 7.87 | 16.75 | 11.33 | 5.67 | 1.64 | PASS @ 10 MPa SCREENING | CONDITIONAL — DESIGN PRESSURE UNRESOLVED | VIABLE SCREENING ALTERNATIVE |
| 53.975 | 2.125 | 3.50 | 46.98 | 12.05 | 14.00 | 6.33 | 3.16 | 0.92 | PASS @ 10 MPa SCREENING | CONDITIONAL — DESIGN PRESSURE UNRESOLVED | VIABLE SCREENING ALTERNATIVE |
| 53.975 | 2.125 | 4.00 | 45.98 | 11.05 | 15.85 | 9.45 | 4.72 | 1.37 | PASS @ 10 MPa SCREENING | CONDITIONAL — DESIGN PRESSURE UNRESOLVED | VIABLE SCREENING ALTERNATIVE |
| 57.150 | 2.250 | 3.50 | 50.15 | 15.22 | 13.28 | 5.33 | 2.67 | 0.77 | PASS @ 10 MPa SCREENING | CONDITIONAL — DESIGN PRESSURE UNRESOLVED | VIABLE SCREENING ALTERNATIVE |
| 57.150 | 2.250 | 4.00 | 49.15 | 14.22 | 15.03 | 7.96 | 3.98 | 1.15 | PASS @ 10 MPa SCREENING | CONDITIONAL — DESIGN PRESSURE UNRESOLVED | VIABLE SCREENING ALTERNATIVE |

Full matrix: `results/compact-casing/compact_casing_id_od_envelope.csv`.

### Actual Hardware Measurement Checklist

**ACTUAL HARDWARE MEASUREMENT REQUIRED** — current nominal envelopes remain the screening basis.

- PCM1808 board: actual width; actual thickness/component height; header protrusion; connector protrusion.
- STM32: actual width; height; headers.
- Other electronics: maximum transverse envelope; wiring exits; connector size; bend radius; solder/header protrusion.

Future custom-PCB dimensions remain **INPUT REQUIRED / UNRESOLVED** until entered; no future dimensions are assumed.

1. **"Can we replace the PEEK electronics carrier with a lower-cost nylon-based material for the current 70 °C / 2-hour PertAcoustic downhole tool?"**
   - **For PPA-GF (Solvay Amodel A-1133 HS, 33% GF):**  
     **HIGHER-PERFORMANCE POLYAMIDE ALTERNATIVE / SECONDARY VALIDATION CANDIDATE (procurement and exact carrier validation pending).**
     PPA provides superior stiffness ($E = 11.81\text{ GPa}$ at 70 °C DAM vs 3.70 GPa for PEEK), moderate moisture absorption (0.20% 24h, 1.80% sat), high glass transition temperature ($T_g \approx 125\text{--}135\text{ °C}$), and is an expected lower-cost candidate compared to PEEK. Note that published downhole qualification evidence often cites structural lubricated AS-1133 HS rather than standard A-1133 HS.
   - **For PA66-GF30 (BASF Ultramid A3WG6 HRX BK23591):**  
     **PRIMARY NYLON PROTOTYPE / VALIDATION CANDIDATE (exact 70 °C wet properties and downhole-fluid compatibility unresolved).**
     While Ultramid A3WG6 HRX offers expected lower material cost and excellent injection moldability with automotive-grade hydrolysis resistance, its **high water absorption (1.5–1.9% equilibrium at 50% RH, 5.6–6.3% saturation in water)** creates substantial dimensional swelling risk in the tight sliding bore (initial diametral clearance **0.4000 mm**, radial **0.2000 mm**). Moisture conditioning substantially reduces 23 °C modulus and stress at break; exact 70 °C conditioned mechanical behavior remains unresolved. Compatibility with hot wellbore completion brines, crude hydrocarbons, and sour gas remains unestablished. Therefore, PA66-GF30 remains a prototype/validation candidate only.

2. **"Which material should we manufacture for the first physical carrier prototype?"**
   - **For engineering benchmark / reference:**
     **Victrex 450G PEEK** remains the **ENGINEERING BENCHMARK / REFERENCE** with the **STRONGEST CURRENT MATERIAL EVIDENCE** (actual PertAcoustic carrier still requires physical validation).
   - **First physical carrier prototype:**
     **BASF Ultramid A3WG6 HRX PA66-GF30** is the first prototype path. Manufacture an exact-grade molded or machined specimen/coupon to verify circuit card retention, connector harness routing, and sliding fit in an Inconel coupon under dry and proposed wet screening conditions.

---

## 2. Exact PA66-GF30 Screening Material Definition (BASF Ultramid A3WG6 HRX)

The candidate nylon material is based strictly on the official manufacturer datasheet for **BASF Ultramid A3WG6 HRX BK23591**:

- **Grade:** BASF Ultramid A3WG6 HRX BK23591
- **Polymer Family & Reinforcement:** PA66-GF30 (Polyamide 66 reinforced with 30% standard glass fibers)
- **Manufacturer:** BASF Performance Polymers
- **Density:** $1370\text{ kg/m³}$ (ISO 1183)
- **Thermal Conductivity:** 0.36 W/(m·K) (Datasheet)
- **Specific Heat Capacity:** 1260 J/(kg·K) (Datasheet)
- **Melting Temperature:** $260\text{ °C}$ (ISO 11357)
- **Heat Deflection Temperature:** HDT/A (1.80 MPa) = $245\text{ °C}$; HDT/B (0.45 MPa) = $260\text{ °C}$ (ISO 75-2)
- **Moisture Absorption (Equilibrium, 23 °C / 50% RH):** **1.5 – 1.9 %** (ISO 62)
- **Water Absorption (Saturation in water, 23 °C):** **5.6 – 6.3 %** (ISO 62)
- **Tensile Modulus (23 °C, ISO 527-2):**
  - **Dry (DAM):** $9500\text{ MPa}$ ($9.5\text{ GPa}$)
  - **Conditioned (Moisture-Equilibrated):** $6000\text{ MPa}$ ($6.0\text{ GPa}$) ($-36.8\%\text{ reduction}$)
- **Tensile Stress at Break (23 °C, ISO 527-2):**
  - **Dry (DAM):** $185\text{ MPa}$
  - **Conditioned:** $110\text{ MPa}$ ($-40.5\%\text{ reduction}$)
  - **Strength Basis:** `TENSILE_STRESS_AT_BREAK_SCREENING` (Glass-reinforced polyamides exhibit brittle failure without ductile yield)
- **Tensile Strain at Break (23 °C):** Dry = $3.7\%$; Conditioned = $7.2\%$
- **Flexural Modulus (23 °C, ISO 178):** Dry = $9200\text{ MPa}$; Conditioned = $5800\text{ MPa}$
- **Tensile Creep Modulus (1000 h, strain $\le 0.5\%$, 23 °C, Conditioned, ISO 899-1):** $4800\text{ MPa}$
- **Coefficient of Linear Thermal Expansion (CLTE, ISO 11359-2):**
  - Along flow: $30\times 10^{-6}\text{ /K}$ ($30\text{ ppm/K}$)
  - Cross-flow: $70\times 10^{-6}\text{ /K}$ ($70\text{ ppm/K}$)
- **Electrical Properties (IEC 62631, BASF Feb 2026 Product Information):**
  - Volume Resistivity: $8\times 10^{10}\text{ }\Omega\cdot\text{m}$ (published table has incomplete dry/conditioned breakdown; separate dry/conditioned values UNAVAILABLE / NOT PUBLISHED)
  - Surface Resistivity: $8\times 10^{12}\text{ }\Omega$ (published table has incomplete dry/conditioned breakdown; separate dry/conditioned values UNAVAILABLE / NOT PUBLISHED)
- **Processing Conditions (BASF Processing Data Sheet):**
  - Melt Temperature: $280\text{--}300\text{ °C}$ | Mold Temperature: $80\text{--}90\text{ °C}$
  - Pre-drying: $80\text{ °C}$ for 4 hours
  - Recommended Pellet Moisture: **0.025 – 0.045 %**
- **70 °C Property Classification:**  
  `CONDITIONAL — EXACT 70 C CONDITIONED PROPERTY NOT VERIFIED`  
  *(Moisture conditioning substantially reduces 23 °C modulus and stress at break; exact 70 °C conditioned mechanical behavior remains unresolved).*

---

## 3. Hydrolysis-Resistant Grade Context & Wellbore Fluid Compatibility

BASF designates Ultramid A3WG6 HRX as a *glass-fibre-reinforced injection moulding grade with enhanced resistance to hydrolysis and heat ageing*. It was specifically developed for automotive cooling circuits exposed to hot water/glycol mixtures.

> **Engineering Boundary:** Automotive cooling-circuit performance does **NOT** constitute verified downhole oilfield compatibility.

The following downhole environmental exposures remain **UNVERIFIED** for PA66-GF30:
1. **Hot completion brines** ($CaCl_2$, $ZnBr_2$, $NaCl$ solutions at 70 °C).
2. **Crude oil and liquid hydrocarbons** (aromatic swelling and extraction of plasticizers).
3. **Drilling and completion fluids** (oil-based muds, synthetic esters, amine-treated muds).
4. **Sour gas ($H_2S$) and dissolved $CO_2$ acid gas exposure**.
5. **Long-duration immersed dimensional stability at 70 °C** (hydrothermal swelling and microcracking).

---

## 4. Focused Carrier Material Trade Matrix

| Property / Criterion | Victrex 450G PEEK | Solvay Amodel A-1133 HS PPA | BASF Ultramid A3WG6 HRX PA66-GF30 |
|---|---|---|---|
| **Polymer Family** | PEEK (Unfilled) | PPA (Polyphthalamide) | PA66 (Polyamide 66) |
| **Reinforcement** | None (Unfilled) | 33% Glass Fiber | 30% Glass Fiber |
| **Density** | 1300 kg/m³ | 1480 kg/m³ | 1370 kg/m³ |
| **Tensile Modulus** | 23 °C DAM: 4000 MPa | PPA 23 °C DAM: 13400 MPa<br>PPA 100 °C DAM: 10800 MPa<br>PPA 70 °C: 11813 MPa<br>`DERIVED / INTERPOLATED SCREENING — DAM` | 23 °C dry: 9500 MPa<br>23 °C conditioned: 6000 MPa<br>70 °C wet: UNRESOLVED |
| **Strength Basis & Value** | `TENSILE_STRENGTH`<br>23 °C: 100 MPa | `TENSILE_STRESS_AT_BREAK`<br>PPA 23 °C DAM: 233 MPa<br>PPA 100 °C DAM: 148 MPa<br>PPA 70 °C: 181 MPa<br>`DERIVED / INTERPOLATED SCREENING — DAM` | `TENSILE_STRESS_AT_BREAK`<br>23 °C dry: 185 MPa<br>23 °C conditioned: 110 MPa<br>70 °C wet: UNRESOLVED |
| **Thermal Conductivity** | 0.29 W/(m·K) | 0.26 W/(m·K) | 0.36 W/(m·K) |
| **Specific Heat Capacity** | 1500 J/(kg·K) | 1200 J/(kg·K) | 1260 J/(kg·K) |
| **Moisture Absorption (Eq 50% RH)** | 0.10% (24h) / 0.50% (sat) | 0.20% (24h) / 1.80% (sat) | **1.5 – 1.9 %** |
| **Water Absorption (Saturation in water)** | **0.50%** | **1.80%** | **5.6 – 6.3 %** |
| **CLTE (Cross-flow / Flow)** | 55 / 45 ppm/K | 55 / 22 ppm/K | 70 / 30 ppm/K |
| **70 °C Property Confidence** | `VERIFIED / INTERPOLATED` | `DERIVED / INTERPOLATED SCREENING — DAM` | `CONDITIONAL — EXACT 70 C CONDITIONED PROPERTY NOT VERIFIED` |
| **1000h Creep Modulus (23 °C Cond)** | High (Tg = 143 °C) | High (10.8 GPa @ 100 °C) | 4800 MPa (70 °C wet unverified) |
| **Dimensional Risk in Tight Bore** | `LOW` | `LOW-TO-MODERATE` | `HIGH DIMENSIONAL RISK` |
| **Downhole Fluid Compatibility** | `STRONGEST EVIDENCE` | `PROVISIONAL / CONDITIONAL` | `UNVERIFIED / HIGH RISK` |
| **Manufacturability & Processing** | High melt temp (380 °C); excellent CNC | Standard high temp (320 °C); abrasive GF | Excellent molding (280 °C); drying req (0.025-0.045%); GF abrasive |
| **Relative Cost Class** | `HIGH COST CLASS` | `EXPECTED LOWER-COST CANDIDATE — PROCUREMENT UNVERIFIED` | `EXPECTED LOWER-COST CANDIDATE — PROCUREMENT UNVERIFIED` |
| **Overall Carrier Classification** | **`ENGINEERING BENCHMARK / REFERENCE`** | **`HIGHER-PERFORMANCE POLYAMIDE ALTERNATIVE / SECONDARY VALIDATION CANDIDATE`** | **`PRIMARY NYLON PROTOTYPE / VALIDATION CANDIDATE`** |

---

## 5. Carrier Sizing, Tolerance & Dimensional Conditioning Sensitivity

Inside the 37.45 mm Inconel shell bore, the carrier chassis must maintain free sliding during assembly (20 °C) and operation (70 °C) without binding or pinching circuit cards.

### Assumed Dimensional-Conditioning Sensitivity Sweep:
*Note: Dimensional-conditioning allowances represent an explicit sensitivity sweep over assumed radial growth, NOT a direct conversion from water-absorption mass percentage.*

| Material | Carrier Nom OD | Initial Diam Clearance | Assumed Hot/Wet Allowance | Diff Thermal Growth | Hot Clearance (Nom) | Remaining Diam Clearance | Interference | Avail Guide Wall | Sliding Status |
|---|---|---|---|---|---|---|---|---|---|
| **PEEK** | 37.050 mm | 0.4000 mm | +0.010 mm | +0.0775 mm | 0.3125 mm | **+0.3125 mm** | 0.0000 mm | `FREE SLIDING` |
| **PEEK** | 37.050 mm | 0.4000 mm | +0.020 mm | +0.0775 mm | 0.3025 mm | **+0.3025 mm** | 0.0000 mm | `FREE SLIDING` |
| **PEEK** | 37.050 mm | 0.4000 mm | +0.040 mm | +0.0775 mm | 0.2825 mm | **+0.2825 mm** | 0.0000 mm | `FREE SLIDING` |
| **PPA** | 37.050 mm | 0.4000 mm | +0.020 mm | +0.0775 mm | 0.3025 mm | **+0.3025 mm** | 0.0000 mm | `FREE SLIDING` |
| **PPA** | 37.050 mm | 0.4000 mm | +0.030 mm | +0.0775 mm | 0.2925 mm | **+0.2925 mm** | 0.0000 mm | `FREE SLIDING` |
| **PPA** | 37.050 mm | 0.4000 mm | +0.060 mm | +0.0775 mm | 0.2625 mm | **+0.2625 mm** | 0.0000 mm | `FREE SLIDING` |
| **PA66** | 37.050 mm | 0.4000 mm | +0.040 mm | +0.1053 mm | 0.2547 mm | **+0.2547 mm** | 0.0000 mm | `FREE SLIDING` |
| **PA66** | 37.050 mm | 0.4000 mm | +0.080 mm | +0.1053 mm | 0.2147 mm | **+0.2147 mm** | 0.0000 mm | `FREE SLIDING` |
| **PA66** | 37.050 mm | 0.4000 mm | +0.120 mm | +0.1053 mm | 0.1747 mm | **+0.1747 mm** | 0.0000 mm | `FREE SLIDING` |
| **PA66** | 37.050 mm | 0.4000 mm | +0.200 mm | +0.1053 mm | 0.0947 mm | **+0.0947 mm** | 0.0000 mm | `FREE SLIDING` |
| **PA66** | 37.050 mm | 0.4000 mm | +0.300 mm | +0.1053 mm | -0.0053 mm | **-0.0053 mm** | 0.0053 mm | `RISK OF BINDING / INTERFERENCE` |
| **PA66** | 36.850 mm | 0.6000 mm | +0.040 mm | +0.1046 mm | 0.4554 mm | **+0.4554 mm** | 0.0000 mm | `FREE SLIDING` |
| **PA66** | 36.850 mm | 0.6000 mm | +0.080 mm | +0.1046 mm | 0.4154 mm | **+0.4154 mm** | 0.0000 mm | `FREE SLIDING` |
| **PA66** | 36.850 mm | 0.6000 mm | +0.120 mm | +0.1046 mm | 0.3754 mm | **+0.3754 mm** | 0.0000 mm | `FREE SLIDING` |
| **PA66** | 36.850 mm | 0.6000 mm | +0.200 mm | +0.1046 mm | 0.2954 mm | **+0.2954 mm** | 0.0000 mm | `FREE SLIDING` |
| **PA66** | 36.850 mm | 0.6000 mm | +0.300 mm | +0.1046 mm | 0.1954 mm | **+0.1954 mm** | 0.0000 mm | `FREE SLIDING` |

### Sizing Observations:
- The live table uses shell bore **37.450 mm**, nominal carrier OD **37.050 mm**, and initial diametral clearance **0.4000 mm**.
- For PA66-GF30 at the nominal assumed allowance (0.080 mm), remaining worst-case diametral clearance is **+0.2147 mm**.
- At the 0.200 mm and 0.300 mm assumed sensitivity cases, remaining clearance is **+0.0947 mm** and **-0.0053 mm**, respectively; any negative result represents **0.0053 mm diametral interference**. These are assumed screening sensitivities, not verified swelling values.

---

## 6. Short-Duration Creep & Thermal Assessment

### Creep Assessment during 2-Hour Exposure:
- 23 °C conditioned creep evidence exists for PA66-GF30 ($4800\text{ MPa}$ at 1000h, ISO 899-1); 70 °C wet creep remains unresolved.
- For the nominal **2.0 hours (7200 s)** PertAcoustic logging run, the short duration reduces concern under internal self-weight and card-retention loads, but does not establish formal creep qualification.

### Thermal Comparison:
- Thermal conductivities: PEEK (0.29 W/(m·K)), PPA (0.26 W/(m·K)), PA66-GF30 (0.36 W/(m·K)).
- PA66-GF30 bulk thermal conductivity is approximately 0.36 W/(m·K) where supported, but this value does not prove electronics cooling. Actual electronics temperature depends on PCB → supports/carrier → contacts/gaps → shell → environment.
- With a fixed outer 70 °C Dirichlet boundary, the 2-hour inner-shell result is a shell-coupled lower-bound screening result (**70.00 °C** at 1.0 W); it does not establish PCB, junction, cavity, or wellbore heat-transfer temperatures. The internal PCB/carrier/contact/gap thermal resistance remains unresolved.
- The allowable internal thermal resistance budget remains **15.00 K/W** for verified +85 °C electronics.

---

## 7. Manufacturing & Processability Comparison

1. **Injection Molding:**
   - **PA66-GF30:** Excellent moldability at standard melt temperatures ($280\text{--}300\text{ °C}$) and mold temperatures ($80\text{--}90\text{ °C}$). Requires pre-drying at $80\text{ °C}$ (4 h) to recommended pellet moisture of $0.025\text{--}0.045\%$ to prevent hydrolytic degradation during processing.
   - **PPA-GF:** High-temperature molding ($315\text{--}330\text{ °C}$) with heated molds ($135\text{--}150\text{ °C}$) required to achieve full crystallinity.
   - **PEEK:** Ultra-high-temperature molding ($380\text{--}400\text{ °C}$) requiring specialized high-temp injection equipment and mold heaters ($160\text{--}190\text{ °C}$).
2. **Prototype Manufacturing:**
   - **Unfilled PEEK:** Outstanding machinability from standard stock plate/rod, producing smooth burr-free card grooves.
   - **PPA-GF & PA66-GF30:** Injection molded exact grade, or CNC machining of exact-grade molded stock/coupons using polycrystalline diamond (PCD) or coated carbide tooling (note: additive manufacturing / 3D printing is unsupported for the exact BASF A3WG6 HRX granule grade).

---

## 8. Proposed Future Physical Validation Plan (Wet / 70 °C Testing)

### PA66-GF30 NYLON CARRIER PHYSICAL VALIDATION PLAN

**PROPOSED SCREENING TEST CONDITIONS — NOT AUTHORITATIVE QUALIFICATION REQUIREMENTS**

Field input from Pak Afif indicates that nylon is used in an Elnusa downhole/wireline context. The exact Elnusa component architecture, nylon grade, pressure exposure, temperature rating, and qualification basis have not been independently verified. This information motivates the PA66 prototype path only; it is not material qualification evidence.

Because PA66 moisture absorption is substantial, the following empirical screening test plan is proposed. It is not completed evidence:

1. **As-Machined / Molded Baseline Inspection:**
   - Measure carrier OD, length, card-guide slot width, and total dry mass ($M_0$).
2. **Water / Brine Conditioning Immersion:**
   - Immerse carrier test coupons in the currently proposed simulated completion brine (3% KCl / NaCl solution) at 23 °C and 70 °C.
   - Measure mass change, critical dimensions, and diametral change after 24h, 48h, 168h (1 week), and saturation; do not estimate dimensional change from mass absorption percentage.
3. **Inconel Bore Sliding Coupon Test:**
   - Slide conditioned wet carrier coupons through an Inconel 718 tube bore coupon (ID $37.45\pm 0.02\text{ mm}$) at 20 °C and inside a 70 °C heated chamber.
   - Record insertion/extraction force and assess binding against a pre-agreed prototype criterion; do not treat this screening criterion as a qualification requirement.
4. **PCB Card Guide Fit & Retention Test:**
   - Measure PCB card-edge insertion force into the guide slots before and after 70 °C hydrothermal conditioning to verify slot width does not swell shut or pinch circuit boards.
5. **Post-exposure inspection:**
   - Record dimensional change, permanent versus recoverable change where observable, interference/binding, cracking, warping, visual degradation, and mass change.
6. **Decision gate:**
   - If PA66 remains dimensionally compatible, intact, and practical to assemble at 70 °C under representative wet exposure, retain it as the preferred low-cost nylon prototype path.
   - If PA66 shows unacceptable swelling, binding, creep, degradation, or instability, evaluate PPA A-1133 HS as the next polyamide candidate; if both fail carrier requirements, retain/revert to the PEEK benchmark architecture.

Actual service-fluid compatibility remains **UNRESOLVED** unless an authoritative fluid specification becomes available.

---

## 9. Side-by-Side Architecture Comparison Matrix

Evaluated under 70 °C external boundary and 7200 s (2h) exposure:

| Architecture | Casing Material | Carrier / Liner | Wall mm | Shell Bore ID | Packaging Feasibility | Inner Shell Temp @ 1W | FoS Buckle (10k psi) | Classification |
|---|---|---|---|---|---|---|---|---|
| **Architecture A: Inconel 718 + Discrete PEEK Carrier (3.5 mm Wall)** | Inconel718 | Conformal Rails (PEEK) | 3.50 | 37.45 mm | FEASIBLE | 70.00 °C | 1.64 | RECOMMENDED BASELINE |
| **Architecture A (4.0 mm Wall): Inconel 718 + Discrete PEEK Carrier** | Inconel718 | Conformal Rails (PEEK) | 4.00 | 36.45 mm | FEASIBLE | 70.00 °C | 2.45 | SCREENING CANDIDATE |
| **Architecture B: Inconel 718 + Discrete PPA Carrier (3.5 mm Wall)** | Inconel718 | Conformal Rails (PPA) | 3.50 | 37.45 mm | FEASIBLE | 70.00 °C | 1.64 | SCREENING CANDIDATE |
| **Architecture B2: Inconel 718 + Discrete PA66-GF30 Carrier (3.5 mm Wall)** | Inconel718 | Conformal Rails (PA66) | 3.50 | 37.45 mm | FEASIBLE | 70.00 °C | 1.64 | SCREENING CANDIDATE |
| **Architecture C: Inconel 718 + Full PEEK Liner (3.5 mm Wall)** | Inconel718 | Full Liner (PEEK) | 3.50 | 37.45 mm | INFEASIBLE | 70.09 °C | 1.64 | INFEASIBLE |
| **Architecture D: Inconel 718 + Full PPA Liner (3.5 mm Wall)** | Inconel718 | Full Liner (PPA) | 3.50 | 37.45 mm | INFEASIBLE | 70.10 °C | 1.64 | INFEASIBLE |
| **Architecture D2: Inconel 718 + Full PA66-GF30 Liner (3.5 mm Wall)** | Inconel718 | Full Liner (PA66) | 3.50 | 37.45 mm | INFEASIBLE | 70.07 °C | 1.64 | INFEASIBLE |
| **Reference Baseline (Arch E): Inconel 718 + Aerogel + PEEK** | Inconel718 | Full Liner (PEEK) | 3.50 | 37.45 mm | INFEASIBLE | 71.72 °C | 1.64 | INFEASIBLE |
| **Architecture F: PEEK-Only Pressure Casing (Exploratory)** | PEEK | None (PEEK) | 7.22 | 30.00 mm | INFEASIBLE | 70.41 °C | 0.29 | EXPLORATORY |
| **Architecture G: PPA-Only Pressure Casing (Exploratory)** | PPA_Amodel_A1133HS | None (PPA) | 7.22 | 30.00 mm | INFEASIBLE | 70.46 °C | 0.93 | EXPLORATORY |
| **Architecture G2: PA66-GF30-Only Pressure Casing (Exploratory)** | PA66_Ultramid_A3WG6_HRX | None (PA66) | 7.22 | 30.00 mm | INFEASIBLE | 70.33 °C | 0.47 | EXPLORATORY |
| **Architecture A: Inconel 718 + Discrete PEEK (OD 47.62 mm)** | Inconel718 | Conformal Rails (PEEK) | 3.50 | 40.62 mm | FEASIBLE | 70.00 °C | 1.34 | SCREENING CANDIDATE |
| **Architecture A: Inconel 718 + Discrete PEEK (OD 50.80 mm)** | Inconel718 | Conformal Rails (PEEK) | 3.50 | 43.80 mm | FEASIBLE | 70.00 °C | 1.10 | SCREENING CANDIDATE |
| **Architecture A: Inconel 718 + Discrete PEEK (OD 53.98 mm)** | Inconel718 | Conformal Rails (PEEK) | 3.50 | 46.98 mm | FEASIBLE | 70.00 °C | 0.92 | SCREENING CANDIDATE |
| **Architecture A: Inconel 718 + Discrete PEEK (OD 57.15 mm)** | Inconel718 | Conformal Rails (PEEK) | 3.50 | 50.15 mm | FEASIBLE | 70.00 °C | 0.77 | SCREENING CANDIDATE |

---

## 10. Thermal Screening & Internal Resistance Budgets

- **External Boundary:** 70.0 °C constant Dirichlet on casing outer diameter.
- **Duration:** 7200 s (2.0 hours).
- **Result Type:** `IDEAL SHELL-COUPLED LOWER-BOUND TEMPERATURE (INNER SHELL SURFACE)`
- **Allowable Internal Thermal Resistance Budget:** **15.00 K/W** (for +85 °C IC limits).

### Internal Thermal-Resistance Parameter Sweep:
| Internal Thermal Resistance $R_{\text{internal}}$ | Internal Temperature Rise $\Delta T$ | Electronics Screening Temp | +85 °C IC Limit Status | Notes |
|---|---|---|---|---|
| 0.0 K/W | +0.0 K | **70.00 °C** | `WITHIN 85C BOUND` | Lumped screening parameter |
| 5.0 K/W | +5.0 K | **75.00 °C** | `WITHIN 85C BOUND` | Lumped screening parameter |
| 10.0 K/W | +10.0 K | **80.00 °C** | `WITHIN 85C BOUND` | Lumped screening parameter |
| 15.0 K/W | +15.0 K | **85.00 °C** | `WITHIN 85C BOUND` | Lumped screening parameter |
| 20.0 K/W | +20.0 K | **90.00 °C** | `EXCEEDS 85C BOUND` | Lumped screening parameter |
| 25.0 K/W | +25.0 K | **95.00 °C** | `EXCEEDS 85C BOUND` | Lumped screening parameter |

---

## 11. Structural Screening Across Pressure Scenarios (Architecture A: Inconel 718 + Discrete PEEK Carrier (3.5 mm Wall))

*Authoritative casing design pressure remains unresolved. Sizing is based on preliminary engineering screening. PA66 is NOT ELIGIBLE AS THE CURRENT PRESSURE-SHELL BASELINE. Polymer-only casing remains EXPLORATORY / CONDITIONAL because authoritative field pressure, creep and collapse requirements remain unresolved.*

1. **Scenario A (~10 MPa / 1,450 psi - ~1000 m Hydrostatic Context):**
   - Max von Mises Stress: **59.7 MPa** | Strength Ratio: **16.75** | Buckling FoS: **11.33**
2. **Scenario B (20 MPa / 2,900 psi - Intermediate Sensitivity):**
   - Max von Mises Stress: **119.4 MPa** | Strength Ratio: **8.38** | Buckling FoS: **5.67**
3. **Scenario C (68.95 MPa / 10,000 psi - Historical Biweekly 5 Benchmark):**
   - Max von Mises Stress: **411.6 MPa** | Strength Ratio: **2.43** | Buckling FoS: **1.64**

---

## 12. CAD Assembly & Dimensional Extent

- **Collision Check:** Automated Boolean intersection checks confirmed **zero prohibited interference (0.00 mm³)**.
- **Modeled Subassembly Span:** **656.9 mm** (Limit $\le 2000.0\text{ mm}$).
- **CAD Assembly Bounding Extent:** **656.9 mm** along axial Z.

---

## 13. Artifacts & Generated Evidence

- **CAD STEP Model:** [`results/compact-casing/cad/compact_casing_assembly.step`](file:///home/faliq/projects/pertacoustic-3d-design/results/compact-casing/cad/compact_casing_assembly.step)
- **Trade Study Dataset:** [`results/compact-casing/compact_casing_trade_study.csv`](file:///home/faliq/projects/pertacoustic-3d-design/results/compact-casing/compact_casing_trade_study.csv)
- **Visualizations:**
  - 3D CAD Assembly Render: [`results/compact-casing/figures/compact_cad_assembly.png`](file:///home/faliq/projects/pertacoustic-3d-design/results/compact-casing/figures/compact_cad_assembly.png)
  - Transverse Cross-Section (Conformal Clearance & Card Guides): [`results/compact-casing/figures/compact_transverse_pcm1808_section.png`](file:///home/faliq/projects/pertacoustic-3d-design/results/compact-casing/figures/compact_transverse_pcm1808_section.png)
  - Longitudinal Section: [`results/compact-casing/figures/compact_longitudinal_section.png`](file:///home/faliq/projects/pertacoustic-3d-design/results/compact-casing/figures/compact_longitudinal_section.png)
  - Thermal History & Comparison: [`results/compact-casing/figures/compact_thermal_trade_study.png`](file:///home/faliq/projects/pertacoustic-3d-design/results/compact-casing/figures/compact_thermal_trade_study.png)

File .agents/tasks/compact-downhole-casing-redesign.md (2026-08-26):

---
title: Compact Downhole Casing Redesign
document_id: AGENT-TASK-002
version: 1.2
status: Validated/Published
language: en-US
last_updated: 2026-08-26
scope:
  - compact downhole casing design
  - electronics packaging and clear ID feasibility
  - geometric, structural, and thermal trade study
  - HTI-02-DHPC/D interface integration
  - preliminary engineering screening
authority_note: A published validated task authorizes only the bounded implementation scope explicitly defined by the task and applicable approved repository authority. Observed repository evidence governs claims about current implementation reality but does not silently redefine the task or its intended authority.
---

# Executable Task

This file defines a bounded software-delivery contract for the PertAcoustic 3D compact downhole casing redesign.

A validated task MUST provide enough authority, scope, acceptance, verification, and stop-condition information for an Executor to proceed without inventing material product, requirement, architecture, scope, or approval decisions.

This is an umbrella task covering internal packaging investigation, geometry sizing, structural screening, 2-hour transient thermal simulation, and HTI-02-DHPC/D interface integration.

## Task identity

**Task title:**  
Compact Downhole Casing Redesign: Geometry, Packaging, Thermal, and Structural Screening

**Task path:**  
`.agents/tasks/compact-downhole-casing-redesign.md`

**Task contract state:**  
Validated/Published

The task file is the executable delivery contract.

Execution and review lifecycle states such as `In Execution`, `Review Required`, `Remediation Required`, and `Accepted` SHOULD normally be tracked by orchestration, review records, repository metadata, or another mechanism that preserves the exact governing task revision.

A lifecycle-status update MUST NOT silently replace the immutable task revision that governed an execution attempt.

When remediation materially changes this executable contract, edit this same stable task path, return it to Draft as needed, and republish it as a new immutable governing task revision before renewed execution.

**Delivery objective / Work Package / MVP:**  
PertAcoustic Downhole Casing Compact Redesign (20 August 2026 Direction)

**Owner / designated planning authority:**  
PertAcoustic Research Collaboration / Designated Technical Authority

## Delivery context

Historical Biweekly 5 work investigated a preliminary 200 mm (7.87 in) OD, 425 mm long casing concept designed for a 150 °C external environment, 1-hour exposure duration, and 10,000 psi screening pressure with a 41 mm clear ID for a legacy board layout.

Under the 20 August 2026 design direction, the operational envelope is refocused on a representative ~1000 m deployment context with an external ambient temperature of 70 °C and a conservative 2-hour (7200 s) thermal exposure duration. The geometric constraints require exploring a preferred casing OD of 1.75 in (44.45 mm), an absolute maximum casing OD of 2.25 in (57.15 mm), a maximum overall tool length of 2.0 m (2000 mm), and preserving mechanical interface compatibility with the HTI-02-DHPC/D hydrophone outline. User notes also reference contextual downhole information regarding nominal 2-7/8 in tubing and a 2.441 in dimension (recorded only as a user-provided tubing/bore-related dimension whose exact meaning remains pending confirmation, and which must not become another PertAcoustic casing OD requirement).

Crucially, the redesign must investigate whether an internal clear diameter of approximately 30 mm is physically feasible for the downhole electronics packaging (incorporating the currently selected PCM1808 ADC, STM32 MCU, power regulation, RTC, SD storage, and wiring harness) rather than assuming 30 mm a priori. MCU or ADC component substitutions are outside the scope of this task.

An objective multi-disciplinary trade study across geometry, packaging clearance, insulation thickness, thermal barrier performance (evaluating the inherited 1 W screening heat load and comparing against justified component operating limits), and structural pressure screening is required. Concluding that 1.75 in OD is infeasible while another diameter ≤ 2.25 in OD satisfies the requirements is an entirely valid, approved engineering outcome. Because authoritative downhole casing design pressure remains unresolved, structural evaluations and final geometry recommendations must explicitly state their underlying pressure assumptions and remain conditional where field pressure authority is absent.

All historical Biweekly 5 reports, code, and simulation results must remain preserved as baseline provenance without modification or overwriting.

## Baseline and task revision

**Implementation baseline:**  
`b33e1622b04ec5e723c634573dbfa93aaa065576`

**Task revision:**  
`resolved when published`

`resolved when published` is a Draft placeholder. It is not sufficient for T5.

Before this task is treated as `Validated/Published` or handed to an Executor, the exact immutable governing task revision MUST be resolvable.

For Git repositories, the preferred published task identity is:

```text
.agents/tasks/compact-downhole-casing-redesign.md @ <full Git commit SHA containing the governing task content>
```

The immutable revision MAY be supplied externally by version-control history, publication metadata, Planner handoff, runtime metadata, or another repository-approved immutable content-identity mechanism. The task body does not need to embed the commit SHA that contains itself.

If establishing the immutable published task revision requires an otherwise unauthorized commit, publication, or other side effect, stop for the applicable authorization. Do not claim the task is Validated/Published while its governing revision remains unresolved.

The implementation baseline and governing task revision are separate references.

Do not change the implementation baseline silently during execution.

If parallel or intervening repository changes require reconciliation, return the issue to planning or follow explicit repository policy.

## Objective

Execute an integrated geometry, electronics packaging, transient thermal, and structural trade study for the compact downhole casing (preferred OD 1.75 in / 44.45 mm, maximum OD 2.25 in / 57.15 mm, maximum overall length 2.0 m, external temperature 70 °C, 2-hour duration, ~1000 m deployment context) interfacing with the nominal HTI-02-DHPC/D hydrophone interface concept. Determine whether 1.75 in OD with ~30 mm clear ID is feasible or identify the recommended feasible envelope based on documented trade-offs ≤ 2.25 in OD, evaluating thermal behavior against verified component operating limits and reporting structural screening under explicit pressure scenarios, while preserving historical Biweekly 5 artifacts intact.

## Authoritative inputs

List of approved sources, working notes, and provenance constraining this task:

### Governing authority

1. **Formal 20 August 2026 Minutes of Meeting (MoM):**
   - External design temperature: 70 °C.
   - Preferred casing OD: 1.75 in (44.45 mm).
   - Maximum casing OD: 2.25 in (57.15 mm).
   - Maximum overall tool length: 2.0 m (2000 mm).
2. **20 August 2026 Meeting Notes (Contextual & Planning Inputs):**
   - Representative deployment / mobilization context: approximately 1000 m depth.
   - Conservative thermal exposure / design duration: 2.0 hours (7200 s).
   - Contextual wellbore / tubing reference: nominal 2-7/8 in tubing and a 2.441 in dimension (user-provided tubing/bore-related dimension whose exact meaning remains pending confirmation; must not become another PertAcoustic casing OD requirement).
3. **Current User Design Direction:**
   - Investigate whether an internal clear diameter of approximately 30 mm is physically feasible for electronics packaging; do NOT assume 30 mm ID is feasible without packaging evidence.
   - Require an objective geometry/packaging/thermal/structural trade study rather than forcing 1.75 in OD to PASS.
4. **Historical Biweekly 5 Evidence & Repository Baseline (`.agents/context/biweekly-5/project.md`, `cosmo/biweekly5.py`):**
   - Baseline screening internal heat load: approximately 1.0 W continuous dissipation (inherited screening scenario).
   - Historical 200 mm OD / 150 °C / 1-hour geometry and baseline CAE simulation pipeline.
   - Historical 10,000 psi (68.9 MPa) screening pressure condition (screening reference scenario only, not an approved design pressure).
   - Historical component-zone temperature extraction logic.
5. **HTI Supplier Mechanical Outline (`.agents/context/biweekly-5/HTI-02-DHPC_D MECH OUTLINE_.pdf`):**
   - Nominal interface concept: 7/16-20 UNF-2A male adapter, separate nominal seal area, conductor routing concept, and exposed acoustic sensing head where supported.
   - Documented limitations: A dimensionally validated connection design does not yet exist; supplier-controlled datums, engagement length, thread tolerances, seal gland geometry, pressure retention, and manufacturing dimensions remain provisional and uncertified unless directly supported by the supplier drawing. Historical Biweekly 5 thread-retention dimensions are screening assumptions, not supplier requirements.
6. **Repository AI Delivery Contract & Materials:**
   - `.agents/AGENTS.md`, `.agents/software-workflow.md`, `.agents/context/project.md`.
   - `cosmo/material_library.json` (Inconel 718, Pyrogel/Aerogel, PEEK, SS316).

### Requirement traceability

- `REQ-GEO-001` (Casing Outer Diameter) → Formal 20 August 2026 MoM: Preferred OD is 1.75 in (44.45 mm); maximum allowable OD is 2.25 in (57.15 mm).
- `REQ-GEO-002` (Overall Length) → Formal 20 August 2026 MoM: Maximum overall tool length is 2.0 m (2000 mm), including housing, endcaps, and HTI interface adapter.
- `REQ-PKG-001` (Internal Electronics Packaging & Clear ID Investigation) → Current User Direction & Hardware Baseline: Investigate whether an internal clear diameter of approximately 30 mm is feasible for the selected electronics stack (currently selected PCM1808 ADC, STM32 MCU, power regulation, RTC, SD storage, interconnects, and wire harness); do not assume 30 mm ID is feasible without physical component layout and radial clearance evidence.
- `REQ-IF-001` (Acoustic Interface Concept) → HTI Supplier Drawing & Historical Provenance: Preserve nominal 7/16-20 UNF-2A interface concept, separate nominal seal area, conductor routing concept, and acoustic head exposure where supported, while explicitly treating engagement length, thread tolerances, seal gland geometry, and pressure retention as provisional engineering screening unless directly supported by the supplier drawing; historical Biweekly 5 thread-retention dimensions may be retained only as explicitly labeled screening assumptions, not supplier requirements.
- `REQ-THM-001` (Thermal Screening & Component Limits) → Formal MoM, Meeting Notes, & Biweekly 5 Baseline: External ambient temperature 70 °C; conservative duration 2 hours (7200 s); inherited screening heat load 1.0 W (with option to report refined hardware estimates alongside 1 W baseline); evaluate results against exact verified part-specific operating temperature limits (STM32F411CEU6 and PCM1808 may use the -40 to +85 °C ranges recorded in the formal 20 August MoM; RTC, SD/storage, power-management, analog-front-end, connectors, batteries, and other selected parts must use exact verified part-specific limits, marking thermal results CONDITIONAL if unverified; do not infer one component's rating for the complete electronics assembly).
- `REQ-STR-001` (Structural Pressure Screening) → Meeting Notes & Historical Provenance: Perform structural screening across explicit pressure scenarios (including ~1000 m hydrostatic context ~10 MPa and the historical 10,000 psi / 68.9 MPa screening benchmark); explicitly document that authoritative casing design pressure remains unresolved and structural recommendations are conditional on field pressure confirmation.
- `REQ-PROV-001` (Historical Provenance & Non-Destructive Separation) → `.agents/context/project.md` & Biweekly 5 Context: Historical Biweekly 5 report, CAD/CAE scripts, and results in `results/biweekly-5/` and `cosmo/biweekly5.py` must remain preserved and unmodified.

Do not use existing implementation as retroactive justification for missing authority.

## Scope

### In scope

- **Electronics Packaging & Clear ID Feasibility Evaluation:**
  - Physical dimension and layout review for the selected hardware components (currently selected PCM1808 ADC, STM32 MCU, power module, RTC, SD, cabling). Packaging rearrangement and axial reorientation are permitted; MCU/ADC component substitution is excluded.
  - Determination of whether ~30 mm clear ID is feasible and establishment of the minimum screening clear ID $D_{\text{clear}}$ supported by the best available verified component/board dimensions and assembly clearances (explicitly labeled provisional when based on nominal/provisional dimensions rather than physical measurements; a manufacturing-exact minimum ID must not be claimed without corresponding dimensional evidence).
- **Structural Pressure Screening & Wall Sizing:**
  - Analytical Lamé stress, von Mises yield FoS, and long-cylinder buckling calculations for Inconel 718 across candidate outer diameters (44.45 mm to 57.15 mm).
  - Parametric evaluation under explicit external pressure scenarios (e.g., ~1000 m hydrostatic context and 10,000 psi legacy screening reference) with explicit notation of unresolved design pressure authority.
- **Parametric Thermal Modeling & Trade Study:**
  - 2-hour (7200 s) transient thermal simulation under 70 °C external ambient boundary.
  - Evaluation of the inherited 1.0 W baseline screening heat load (and comparison with refined hardware dissipation estimates if available).
  - Multi-layer evaluation (Inconel 718 outer barrel, Aerogel insulation layer, PEEK liner) and assessment of component-zone temperatures against exact verified part-specific operating limits (STM32F411CEU6 and PCM1808 per MoM -40 to +85 °C; exact verified limits for RTC, SD, power, AFE, connectors, batteries; marking thermal results CONDITIONAL where unverified; without inferring one component's rating across the complete assembly).
- **Trade Study Matrix & Engineering Recommendation:**
  - Structured trade-off matrix evaluating combinations of OD (44.45 mm / 1.75 in to 57.15 mm / 2.25 in), clear ID, insulation thickness, structural FoS, and 2-hour transient thermal response.
  - Formal engineering conclusion regarding 1.75 in OD feasibility and recommended casing geometry ≤ 2.25 in OD, noting conditional structural/thermal limits where authoritative requirements are unresolved.
- **3D Parametric CAD Assembly:**
  - Parametric CAD models generating the compact casing assembly (housing barrel, endcaps, internal sleeve/carrier, axial buffers, and nominal HTI adapter) with total modeled length ≤ 2.0 m.
  - STEP/assembly export for mechanical visualization.
- **Verification & Automated Testing:**
  - Automated tests verifying compact casing geometry sizing, packaging clearance logic, analytical structural formulas, thermal extraction routines, and nominal HTI thread datums without regressing historical Biweekly 5 tests.

### Out of scope

- Modifying, renaming, or overwriting historical Biweekly 5 code (`cosmo/biweekly5.py`), context (`.agents/context/biweekly-5/`), or results (`results/biweekly-5/`).
- Substituting the PCM1808 ADC or STM32 MCU with different integrated circuits.
- Manufacturing shop drawings, machining G-code, tooling specifications, or certified physical fabrication drawings.
- Physical pressure-vessel certification, API/ASME stamp qualification, or high-temperature well-logging field qualification.
- Physical O-ring seal compound qualification, sour-gas ($H_2S$) qualification, or downhole corrosive wear testing.
- Exotic thermal technologies excluded by UGM lab CNC constraints (vacuum dewar flasks, active Stirling coolers, or active phase-change material blocks).
- Altering the material library unit system or corrupting CalculiX conductivity units.

### Preserved behavior

- Existing Biweekly 5 tests (`tests/test_biweekly5.py`) and compiler tests (`tests/test_results_compiler.py`) continue to pass without regression.
- Core simulation engines (`cosmo/core/cad_generator.py`, `cosmo/core/mesh_generator.py`, `cosmo/core/solver_interface.py`, `cosmo/core/result_extractor.py`) maintain unit consistency and fail-closed error handling.
- Nominal HTI-02-DHPC/D interface concept (nominal 7/16-20 UNF-2A interface concept, separate nominal seal area, conductor routing concept, and acoustic head exposure where supported; engagement length, thread tolerances, seal gland geometry, and pressure retention remain provisional unless directly supported by the supplier drawing, with historical Biweekly 5 thread-retention dimensions retained only as explicitly labeled screening assumptions, not supplier requirements).
- Conventional CNC manufacturability constraint for components fabricated at the UGM Geophysics Laboratory.

## Dependencies and assumptions

### Dependencies

- Python 3.11 environment with CadQuery, Gmsh, NumPy, Matplotlib.
- CalculiX 2.22 solver (`cosmo/ccx/calculix_2.22_4win/ccx_static.exe` or environment-compatible CCX binary).
- Mechanical outline specification: `.agents/context/biweekly-5/HTI-02-DHPC_D MECH OUTLINE_.pdf`.
- Material database: `cosmo/material_library.json`.

### Approved assumptions

- **External Ambient Temperature:** 70 °C constant Dirichlet boundary condition on outer exposed surfaces (Formal MoM).
- **Exposure Duration:** 2.0 hours (7200 seconds) conservative transient thermal exposure (Meeting Notes).
- **Baseline Heat Load:** 1.0 W continuous internal heat dissipation evaluated as an inherited Biweekly 5 screening baseline.
- **Hardware Configuration:** Currently selected PCM1808 ADC and STM32 MCU baseline hardware; packaging orientation and placement may be arranged axially.
- **Objective Trade-Off Rule:** If physics, structural safety, or packaging clearance reveals that 1.75 in (44.45 mm) OD cannot satisfy operational component temperature limits over 2 hours with required structural margin, concluding infeasibility of 1.75 in and recommending a feasible OD ≤ 2.25 in (57.15 mm) is an approved valid outcome.

### Unresolved authority items & conditional assumptions

- **Authoritative Casing Design Pressure:** Unresolved. ~1000 m is deployment context, not an approved design pressure rating. Structural screening will evaluate explicit scenarios (including ~1000 m hydrostatic and 10,000 psi legacy screening), but final structural acceptance remains conditional on client pressure specification.
- **Component Temperature Limits:** The legacy 50 °C optimizer threshold is not an approved design authority. STM32F411CEU6 and PCM1808 may use the -40 to +85 °C ranges recorded in the formal 20 August MoM. For RTC, SD/storage, power-management, analog-front-end, connectors, batteries, and other actual selected parts, use only exact verified part-specific limits. If an exact selected component or its operating-temperature limit cannot be verified, mark that thermal result CONDITIONAL. Do not infer one component's rating for the complete electronics assembly.
- **Supplier-Controlled HTI Interface Geometry:** Unresolved. Supplier-controlled datums, engagement length, exact thread tolerances, seal gland geometry, and pressure retention details remain unverified and provisional unless directly supported by the supplier-controlled drawing. Historical Biweekly 5 thread-retention dimensions are screening assumptions, not supplier requirements.
- **Wellbore / Tubing Context Reference:** The nominal 2-7/8 in tubing and 2.441 in dimension are recorded only as user-provided tubing/bore-related notes whose exact meaning remains pending confirmation; they must not become another PertAcoustic casing OD requirement.

### Remaining approval requirements

- **Task Publication Approval:** Designated technical authority review and approval to publish this task contract from Draft to Validated/Published.
- **Design Pressure & Final Geometry Approval:** Human engineering and client review of the trade study matrix and recommended OD/ID configuration before initiating physical procurement or machining.

## Required capabilities

- Repository read and write
- Local Python command execution in `.venv`
- CadQuery 3D solid modeling and STEP export
- Gmsh finite element mesh generation
- CalculiX FEA execution and FRD parsing
- Automated test execution (`unittest`)

Runtime, model, vendor, reasoning level, or agent implementation SHOULD NOT be encoded here.

## Execution constraints

### Constraints

- **Honest Screening Reporting:** Do not manipulate material properties, heat transfer coefficients, or safety margins to force a "PASS" on the 1.75 in OD candidate. Report true physical screening outputs.
- **Packaging Evidence:** Packaging feasibility for ~30 mm ID must be demonstrated with explicit physical component dimensions, axial stacking, and radial clearances for the selected PCM1808 ADC and STM32 MCU.
- **Preliminary Screening Status:** All structural, thermal, and packaging results must be explicitly designated as preliminary engineering screening, not manufacturing certification or commercial rating.
- **Unit and Solver Integrity:** Maintain strict SI/CalculiX unit conventions (Conductivity in $\text{W}/(\text{m}\cdot\text{K})$, dimensions in mm, pressures/stresses in MPa).
- **Reuse and Historical Separation:** Reuse existing repository CAD/CAE mechanisms where appropriate; ensure all new outputs and code maintain clean separation from historical Biweekly 5 artifacts.

## Acceptance criteria

- [ ] **Packaging Feasibility Assessment:** Packaging analysis objectively investigates and documents whether the selected electronics (PCM1808 ADC, STM32 MCU, power, sensors, wiring) can package within ~30 mm clear ID (or establishes the minimum screening clear ID $D_{\text{clear}}$ supported by the best available verified component/board dimensions and assembly clearances, explicitly labeling the result provisional when based on nominal/provisional dimensions rather than physical measurements; a manufacturing-exact minimum ID must not be claimed without corresponding dimensional evidence).
- [ ] **Parametric Trade Study Execution:** Trade study evaluates casing ODs across the range from preferred 1.75 in (44.45 mm) to maximum 2.25 in (57.15 mm), varying Inconel wall thickness and Aerogel insulation thickness under 70 °C ambient and 2-hour duration.
- [ ] **Thermal Screening & Component Limits:** 2-hour (7200 s) transient thermal simulation reports internal cavity and zone temperatures under the inherited 1.0 W screening heat load, comparing results against exact verified part-specific operating limits (STM32F411CEU6 and PCM1808 per MoM -40 to +85 °C; exact verified limits for RTC, SD, power, AFE, connectors, batteries; marking thermal results CONDITIONAL where unverified, without inferring one component's rating for the complete assembly).
- [ ] **Structural Screening & Pressure Scenarios:** Structural calculations determine Lamé stresses, von Mises yield safety factors, and buckling factors under explicit pressure scenarios (including ~1000 m hydrostatic context and 10,000 psi legacy screening), explicitly documenting that authoritative field design pressure remains unresolved.
- [ ] **Trade Study Matrix & Recommendation:** A structured trade-off matrix clearly presents OD vs. clear ID vs. insulation thickness vs. structural FoS vs. 2-hour transient thermal response, providing a definitive recommendation on the feasibility of 1.75 in OD and the recommended feasible envelope based on documented trade-offs ≤ 2.25 in OD without exceeding 57.15 mm OD.
- [ ] **3D CAD Assembly:** Parametric CAD model generates the complete compact downhole casing assembly (housing, endcaps, internal sleeve, axial buffers, and nominal HTI adapter) with total modeled length ≤ 2.0 m.
- [ ] **Interface & Historical Preservation:** Nominal HTI-02-DHPC/D interface concept is modeled with explicit provisional assumptions; historical Biweekly 5 files (`cosmo/biweekly5.py`, `results/biweekly-5/`) remain unmodified; all existing tests in `tests/test_biweekly5.py` and `tests/test_results_compiler.py` pass.
- [ ] **Automated Test Coverage:** Automated unit tests in `tests/` verify compact casing geometry sizing, packaging clearance logic, analytical structural formulas, and thermal extraction routines.

## Verification requirements

### Required checks

- `python -m unittest discover -s tests -v` passes with 100% success (including both existing Biweekly 5 regression tests and new compact casing tests).
- Automated execution of the compact casing trade study runner generates complete tabular outputs and comparison plots without manual intervention.
- CadQuery solid verification confirms valid, watertight solids without invalid intersections or disconnected volumes.
- Result extraction routines confirm fail-closed behavior on missing solver steps or malformed outputs.

### Required evidence

The Executor MUST report:
- Implementation revision or exact working-tree state.
- Full output of all executed test suites.
- Complete numerical trade study matrix (OD, ID, wall thickness, insulation thickness, yield FoS, buckling FoS, 2-hour peak internal temperature).
- Final recommendation regarding 1.75 in OD feasibility and selected geometry ≤ 2.25 in OD.
- Justified component temperature limits used and identification of any conditional thermal/structural results.
- Generated CAD STEP files and thermal/structural trade-off comparison plots.
- Confirmation of zero regressions or modifications to Biweekly 5 historical artifacts.

## Stop conditions

The Executor MUST stop implementation and return the issue to planning when:
- Selected electronics (PCM1808 ADC, STM32 MCU, power, sensors) cannot physically fit within the maximum 2.25 in (57.15 mm) OD casing envelope under any valid structural/insulation configuration.
- Exact supplier-controlled HTI interface geometry or certified seal details are required for execution but unavailable from the supplier outline drawing.
- The CalculiX solver consistently fails to converge or exhibits numerical instability across valid mesh configurations.
- Execution requires unauthorized MCU/ADC component substitutions, unapproved external dependencies, or destructive changes to historical files.
- Material ambiguity arises regarding client operational constraints or approval boundaries.

## Side-effect authorization

Implementation authorization is strictly bounded to the task's defined execution scope.

Unless explicitly authorized by this task, applicable repository policy, or designated authority, the task does NOT authorize:
- Git commit, push, or pull-request creation.
- Deployment, external publication, or release tagging.
- Deletion or modification of historical `results/biweekly-5/` or `cosmo/biweekly5.py` files.
- Modification of package dependencies in `pyproject.toml` without prior review.

### Explicitly authorized side effects

- Creation of new compact casing Python modules under `cosmo/`.
- Creation of new compact casing unit tests under `tests/`.
- Creation of new compact casing results, plots, STEP files, and trade study markdown reports under a dedicated results directory (e.g., `results/compact-casing/`).

## Expected terminal outcome

The Executor's implementation phase SHOULD end in **Review Required**:
- Exact implementation revision or working-tree state identified.
- Complete verification results and trade study matrix available.
- Final engineering recommendation regarding 1.75 in vs ≤ 2.25 in OD documented with simulation evidence and explicit pressure/component-limit assumptions for Reviewer evaluation.

## Review and remediation handling

The Reviewer evaluates implementation against the exact governing task revision, applicable authority, implementation baseline, implementation revision, and observed evidence.

If review identifies bounded corrections within the same delivery objective, update and republish this same task file rather than creating filename-version copies.

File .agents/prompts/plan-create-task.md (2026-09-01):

---
title: Plan, Review, and Create Validated Task
document_id: AGENT-PROMPT-PLAN-001
version: 2.4
status: approved-template
language: en-US
last_updated: 2026-08-30
role:
  - Planner
  - Reviewer
scope:
  - current delivery-state assessment
  - implementation and execution-result review
  - implementation acceptance
  - bounded remediation routing
  - planning-gate repair
  - authority and documentation updates
  - requirement and architecture readiness
  - delivery-objective selection
  - validated task creation
  - execution-ready Executor Launcher output
authority_note: This prompt is a reusable Planner/Reviewer delivery-orchestration procedure. It is not repository authority and MUST NOT override .agents/AGENTS.md, .agents/software-workflow.md, approved repository authority, the governing task revision, or observed repository evidence.
---

# Plan, Review, and Create Validated Task

Use this procedure when acting as the repository's **Planner and/or Reviewer**.

Despite the filename, task creation is only one possible outcome.

The purpose of this procedure is to:

1. establish the repository's current delivery state;
2. resolve any already-published task or pending Executor result before planning dependent new implementation work;
3. review pending implementation when it exists, or validate an Executor stop result when execution ended without implementation;
4. determine acceptance, bounded remediation, execution handoff, or return-to-planning as applicable;
5. establish or confirm the current accepted baseline;
6. identify the earliest unmet or materially unreliable protocol gate;
7. repair only the authority, context, requirement, architecture, or planning artifacts actually needed;
8. select the next coherent delivery objective when implementation work is justified;
9. publish a validated executable task only when Task Readiness is satisfied;
10. emit a ready-to-copy Executor Launcher when the final outcome leaves a published task ready for execution; and
11. stop at real approval, authority, dependency, side-effect, or safety boundaries rather than inventing decisions.

This procedure is intended to be invoked repeatedly throughout delivery.

Typical loop:

```text
plan-create-task.md
→ validated task
→ Executor Launcher
→ Executor
→ implementation + evidence
→ plan-create-task.md
→ accept / remediate / return to planning
→ next valid action
```

## Required loading

Before material Planner/Reviewer work, load:

1. `.agents/AGENTS.md`;
2. `.agents/software-workflow.md`;
3. `.agents/context/project.md`;
4. only the scoped context materially relevant to the current work;
5. applicable repository authority;
6. active or recently completed task files and their exact governing revisions;
7. current implementation evidence and repository state;
8. `.agents/tasks/_template.md` when creating or materially updating an executable task.

Additional repository files, Git history, CI evidence, runtime evidence, issues, decisions, external specifications, or operational records MAY be loaded when needed to establish authority, traceability, implementation reality, acceptance, feasibility, or risk.

Use the smallest sufficient context.

Do not load unrelated repository areas merely because they exist.

## Operating principles

Throughout this procedure:

- distinguish **intended authority** from **observed implementation reality**;
- resolve an already-published task or pending Executor result before planning new dependent implementation on the same delivery line;
- review pending implementation before dependent successor planning;
- reuse valid existing artifacts rather than recreating them for formatting consistency;
- do not treat implementation as retroactive business, product, requirement, or architecture authority;
- do not treat approved specifications as proof that implementation satisfies them;
- preserve stable requirement identifiers when they already exist;
- maintain progressive bidirectional traceability;
- do not invent product, requirement, architecture, scope, approval, acceptance, or release decisions;
- do not create unnecessary artifact or filename proliferation;
- prefer repository-established document structure and conventions;
- apply repository reuse discipline before proposing new technical mechanisms;
- keep blocking and non-blocking unresolved items explicit;
- scale documentation and verification depth to complexity, risk, regulation, and change impact;
- separate implementation acceptance from release authorization.

AI-generated authority-bearing artifacts remain **Draft** until approved by the designated authority.

A Draft authority artifact MUST NOT silently become executable authority when approval is required.

## Repository intelligence

Repository-intelligence tools are supporting aids rather than authority.

### Graphify

When available and materially useful, use Graphify for documentation-oriented discovery such as:

- locating relevant business, product, requirement, architecture, and planning artifacts;
- mapping relationships among authoritative documents;
- narrowing the relevant document set;
- identifying potentially duplicated, disconnected, stale, or conflicting documentation;
- checking whether expected upstream/downstream documentation relationships exist.

Prefer sufficiently fresh existing graphs.

Prefer incremental refresh when repository changes are bounded.

Do not treat graph output as authority.

Verify material conclusions against the exact repository sources.

### Codebase Memory MCP

When available and materially useful, use Codebase Memory MCP for implementation-oriented discovery such as:

- locating symbols and implementations;
- finding callers and call paths;
- identifying routes, handlers, services, persistence boundaries, jobs, consumers, and tests;
- understanding dependency and impact surfaces;
- locating established repository patterns;
- identifying reverse-traceability gaps where implementation exists without a legitimate governing requirement or task;
- checking whether a proposed implementation mechanism already exists.

Do not treat indexed or summarized intelligence as implementation proof when the underlying repository can be inspected directly.

Verify material conclusions against current source, configuration, migrations, tests, Git state, CI, or runtime evidence as appropriate.

### Freshness

If a graph, index, summary, cached repository model, context file, or generated analysis may be stale or belong to a different revision, verify directly against the repository before relying on it materially.

---
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

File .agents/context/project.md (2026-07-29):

<!-- code-agent-template:managed -->
# Project Context

**Status:** Verified against the current working tree
**Last verified:** 2026-07-29
**Repository base:** `d71811dc434a32f8631128fa20f4bb2dc890605a`

This file records only repository-observed behavior and explicit user direction. Period-specific reporting context belongs under `.agents/context/biweekly-N/`.

## Purpose

PertAcoustic is a research workspace for developing a 3D casing design for a downhole acoustic tool. The implemented software is currently a Python transient-thermal CAD-CAE prototype for concentric cylindrical casing layers. A dimensionally validated HTI-02-DHPC/D connection design does not yet exist in the cleaned repository.

## Intended Users

- Research collaborators preparing and reviewing PertAcoustic casing designs and biweekly progress reports.
- Engineering users running the local CAD, mesh, CalculiX, and result-extraction workflow.

Evidence: `cosmo/`, `.agents/context/biweekly-2/`, `.agents/context/biweekly-4/`, and `.agents/context/biweekly-5/`.
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

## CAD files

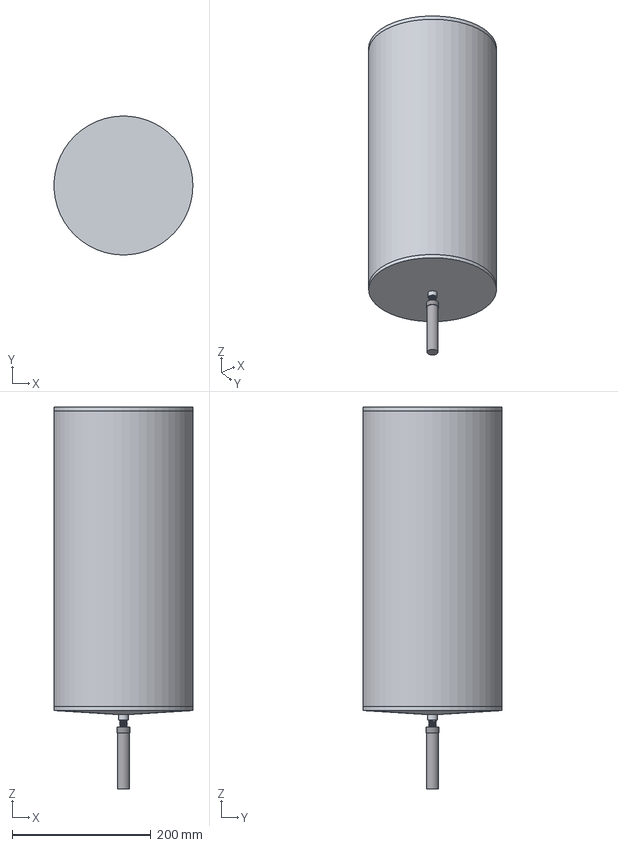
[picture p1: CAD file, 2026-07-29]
results/biweekly-5/cad/hti_casing_detailed.step
199.8 x 199.9 x 549.9 mm
HTI_sensor_reference_envelope
HTI_feedthrough_end
Threaded_front_adapter
Inconel718_pressure_shell
Rear_pressure_endcap
Sealed_aerogel
Axial_aerogel_buffers
PEEK_carrier
Configurable_analog_front_end
PCM1808_provisional_envelope
STM32F411_provisional_envelope
RTC_SD_power_reserve
HTI_pin_1
HTI_pin_2
HTI_pin_3
Wire_-1.3
Wire_0.0
Wire_1.3

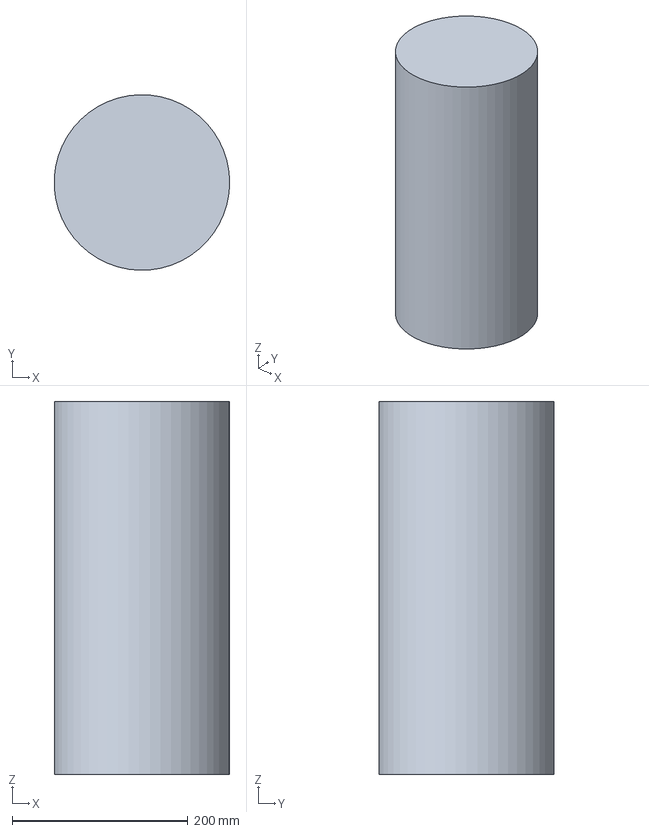
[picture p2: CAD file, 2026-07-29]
results/biweekly-5/cad/hti_casing_analysis.step
199.8 x 199.9 x 425.0 mm
Outer
Insulation
FrontInsulation
RearInsulation
Chassis

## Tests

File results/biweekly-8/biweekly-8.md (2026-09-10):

# PertAcoustic Biweekly 8 Engineering Progress Report

**Document type:** Evidence-based progress report  
**Status:** Review Required  
**Reporting-period dates:** UNRESOLVED - no authoritative Biweekly 6/7/8 date chain was established in repository evidence.  
**Repository evidence cutoff:** `main@667ccd59cf6657a75dfe3cc2b4c67488737ef028`  
**Governing reporting task:** `.agents/tasks/biweekly-8-report.md @ 833cf553f3b08348670588209655e8e18182ec1c`  
**Governing compact-casing task:** `.agents/tasks/compact-downhole-casing-redesign.md @ ad24d9146815f88368d8f6b1d635831d57aed13d`  
**Primary human-facing deliverable:** Native Google Doc `3d-design-biweekly-8`  
**Google Doc URL:** `https://docs.google.com/document/d/1APiwwgRWdYymxyVo5zMt8-UmJUBvw6uppI3421Gw1dA/edit?usp=drivesdk`  
**Google Doc document ID:** `1APiwwgRWdYymxyVo5zMt8-UmJUBvw6uppI3421Gw1dA`  
**Google Drive target folder:** `pertacoustic` (`14V4rGX0lwHmwCNOGn8BQYE-0R6DH-Fy9`)

This report summarizes accepted repository evidence only. It is not a manufacturing drawing, pressure qualification, field qualification, or new engineering source of truth.

The Markdown file remains the repository traceability/source artifact. The native Google Doc is the primary human-facing deliverable and is not an engineering source of truth.

## Executive Progress Summary

PertAcoustic progressed from the historical Biweekly 5 large casing / aerogel-oriented concept to a compact no-aerogel screening architecture. The accepted compact-casing evidence now supports a preferred preliminary envelope of **44.45 mm / 1.75 in OD**, **3.50 mm Inconel 718 pressure-shell wall**, and **37.45 mm shell bore**.

The current electronics packaging screen indicates that the nominal PCM1808 transverse envelope plus **1.0 mm per side** requires approximately **34.93 mm** circular diameter. Against the **37.45 mm** bore, the current preliminary diametral packaging margin is approximately **2.52 mm**. This is a screening calculation, not a physical fit validation.

The current architecture is:

| Item | Current Status |
|---|---|
| Pressure shell | Inconel 718 |
| Preferred OD | 44.45 mm / 1.75 in |
| Maximum screening OD | 57.15 mm / 2.25 in |
| Preliminary wall | 3.50 mm |
| Shell bore | 37.45 mm |
| Internal-diameter direction | ID > 30 mm; 30 mm is a lower bound, not the target design ID |
| Internal packaging strategy | Discrete/conformal polymer electronics carrier inside the Inconel shell |
| Aerogel | No longer part of the current baseline architecture |
| PA66-GF30 | PRIMARY NYLON PROTOTYPE / VALIDATION CANDIDATE |
| PEEK | ENGINEERING BENCHMARK / REFERENCE |
| PPA | HIGHER-PERFORMANCE POLYAMIDE ALTERNATIVE / SECONDARY VALIDATION CANDIDATE |

Structural and thermal outputs remain **PRELIMINARY ENGINEERING SCREENING**. Structural status remains **CONDITIONAL - DESIGN PRESSURE UNRESOLVED**. The current thermal result is an **IDEAL SHELL-COUPLED LOWER-BOUND TEMPERATURE (INNER SHELL SURFACE)**, not PCB, cavity, chip-junction, or electronics qualification evidence.

## Work Completed During The Reporting Period

Because authoritative reporting-period dates are unresolved, this section is bounded by the repository evidence cutoff rather than a calendar range.

- Completed compact ID/OD screening across **44.45 mm to 57.15 mm OD** and **3.50 mm / 4.00 mm** shell-wall candidates.
- Selected the smallest viable preliminary screening geometry: **44.45 mm OD / 37.45 mm bore / 3.50 mm wall**.
- Reframed the architecture from radial aerogel insulation toward an **Inconel shell plus discrete/conformal polymer electronics carrier**.
- Preserved the current electronics selection baseline while identifying that measured board, header, connector, wiring, and bend-radius geometry is still required.
- Classified the polymer carrier options: PA66-GF30 for first prototype validation, PEEK as the strongest current benchmark, and PPA as a secondary higher-performance polyamide candidate.
- Recorded structural pressure cases as screening and sensitivity scenarios rather than design-pressure authority.
- Recorded thermal results as inner-shell lower-bound screening and documented the missing internal electronics thermal path.

## Current Engineering Configuration

| Parameter | Value | Evidence Status |
|---|---:|---|
| Preferred casing OD | 44.45 mm / 1.750 in | VERIFIED from accepted compact-casing envelope |
| Maximum casing OD | 57.15 mm / 2.250 in | VERIFIED from governing compact-casing task and accepted envelope |
| Preliminary shell wall | 3.50 mm | DERIVED SCREENING / recommended preliminary configuration |
| Shell bore | 37.45 mm | DERIVED: 44.45 - 2 x 3.50 = 37.45 mm |
| ID direction | > 30.0 mm | VERIFIED as project floor; not a target ID |
| Electronics-required circular envelope | 34.93 mm | DERIVED SCREENING from PCM1808 30 mm x 12 mm transverse envelope plus 1.0 mm per side |
| Packaging diametral margin | 2.52 mm | DERIVED SCREENING: 37.45 - 34.93 = 2.52 mm |
| Total modeled tool length | 656.9 mm | VERIFIED generated compact-casing evidence |
| Thermal exposure screen | 70 C external, 7200 s / 2 h | VERIFIED from governing task and compact-casing evidence |
| Internal heat input | 1.0 W inherited screening case | ASSUMED SCREENING |

The current packaging result means the nominal screening envelope fits inside the shell bore with limited margin. It does not prove that actual purchased PCBs, solder joints, headers, connectors, wire exits, or cable bend radii fit after measurement and assembly.

## Engineering Analysis

### Mechanical Packaging And ID/OD Envelope

The accepted ID/OD envelope supports the **44.45 mm OD / 3.50 mm wall** configuration as the recommended preliminary geometry because it is the smallest screened OD that satisfies the ID floor, current nominal electronics envelope, and 10 MPa screening structural checks.

| OD (mm) | OD (in) | Wall (mm) | ID (mm) | Electronics Required Diameter (mm) | Packaging Margin (mm) | 10 MPa Buckling FoS | Historical 10k psi Buckling FoS | Recommendation |
|---:|---:|---:|---:|---:|---:|---:|---:|---|
| 44.45 | 1.750 | 3.50 | 37.45 | 34.93 | 2.52 | 11.33 | 1.64 | RECOMMENDED PRELIMINARY CONFIGURATION |
| 44.45 | 1.750 | 4.00 | 36.45 | 34.93 | 1.52 | 16.92 | 2.45 | VIABLE SCREENING ALTERNATIVE |
| 57.15 | 2.250 | 3.50 | 50.15 | 34.93 | 15.22 | 5.33 | 0.77 | VIABLE SCREENING ALTERNATIVE |

The table above is a reporting excerpt. The full accepted matrix is in `results/compact-casing/compact_casing_id_od_envelope.csv`.

### Material And Carrier Selection

The pressure boundary remains the **Inconel 718 shell**. The polymer carrier is an internal support and packaging feature only; it is not a pressure boundary.

| Carrier Material | Current Role | Key Limitation |
|---|---|---|
| PA66-GF30, BASF Ultramid A3WG6 HRX BK23591 | PRIMARY NYLON PROTOTYPE / VALIDATION CANDIDATE | Exact 70 C wet dimensional and mechanical behavior, water swelling, and downhole fluid compatibility remain unresolved |
| Victrex 450G PEEK | ENGINEERING BENCHMARK / REFERENCE | Higher cost class; actual PertAcoustic carrier still requires physical validation |
| Solvay Amodel A-1133 HS PPA | HIGHER-PERFORMANCE POLYAMIDE ALTERNATIVE / SECONDARY VALIDATION CANDIDATE | Procurement and exact carrier validation pending; downhole qualification is not established for the current grade |

PA66-GF30 must not be treated as downhole-qualified. Its manufacturer data supports a screening material definition, but the repository evidence keeps hot/wet dimensional response, water absorption/swelling, long-duration performance, and well-fluid compatibility unresolved.

### Structural Screening

Structural status remains:

```text
CONDITIONAL - DESIGN PRESSURE UNRESOLVED
```

For the recommended **44.45 mm OD / 3.50 mm wall Inconel 718 shell**, accepted screening values are:

| Pressure Case | Correct Classification | Max von Mises Stress | Strength Ratio | Buckling FoS | Reporting Boundary |
|---|---|---:|---:|---:|---|
| ~10 MPa / ~1,450 psi | Screening context | 59.7 MPa | 16.75 | 11.33 | Preliminary screen only |
| 20 MPa / ~2,900 psi | Sensitivity scenario | 119.4 MPa | 8.38 | 5.67 | Preliminary sensitivity only |
| 68.95 MPa / 10,000 psi | Historical comparison | 411.6 MPa | 2.43 | 1.64 | Historical benchmark comparison only |

These factors of safety do not establish pressure qualification. Authoritative field design pressure, collapse criteria, seal pressure retention, fatigue, corrosion, sour-service exposure, and physical pressure testing remain unresolved.

### Thermal Screening

The current accepted thermal result may support statements about shell response and inner-shell lower-bound temperature only:

```text
IDEAL SHELL-COUPLED LOWER-BOUND TEMPERATURE (INNER SHELL SURFACE)
```

For the current no-aerogel compact architecture, the 2-hour / 1 W screening result is **70.00 C** at the inner shell surface. It must not be relabeled as PCB temperature, electronics cavity temperature, STM32 junction temperature, PCM1808 junction temperature, complete electronics temperature, or electronics qualification.

The current result leaves the internal electronics thermal path unresolved. Stronger thermal analysis requires:

```text
environment
-> Inconel shell
-> shell/carrier contact
-> polymer carrier
-> PCB/contact
-> electronics heat sources
```

with measured or justified thermal resistances and representative electronics power dissipation.

### Electronics Packaging

The current **34.93 mm** electronics envelope is provisional. It is derived from the nominal PCM1808 transverse envelope and clearance rule in the accepted compact-casing evidence. Actual hardware measurement is still required for:

- PCM1808 PCB length, width, thickness, component height, headers, connector protrusion, and solder protrusion.
- STM32 board dimensions, headers, component height, and solder protrusion.
- Power, RTC, SD/storage, analog front-end, connector, and wiring transverse envelopes.
- Wiring exits, cable bend radius, strain relief, and assembly sequence.
- Carrier slot dimensions and manufacturing tolerance stack after dry and wet conditioning.

Physical fit validation has not been completed.

### HTI And Acoustic Interface

The HTI-02-DHPC/D interface concept remains provisional. The accepted evidence preserves the nominal **7/16-20 UNF-2A** interface concept, separate pressure-seal area, conductor routing concept, and exposed acoustic sensing head where supported by the local supplier drawing context.

Supplier-controlled datums, engagement length, thread tolerances, seal gland geometry, pressure retention, preamplifier mode, pinout, cable details, and manufacturing dimensions remain unresolved.

## Comparison With Previous Baseline

| Topic | Historical Biweekly 5 Baseline | Current Compact-Casing Evidence |
|---|---|---|
| OD | 200 mm OD thermal-priority concept | 44.45 mm / 1.75 in preferred compact OD |
| Length | 425 mm housing length; historical package report | 656.9 mm modeled compact subassembly span, within 2000 mm maximum |
| Pressure shell | Inconel 718 | Inconel 718 |
| Wall | 35 mm historical screening wall | 3.50 mm preliminary screening wall |
| Internal clear diameter | 41 mm provisional electronics clear ID | 37.45 mm shell bore; 34.93 mm current electronics-required screening envelope |
| Insulation strategy | Aerogel radial layer and axial buffers | No aerogel baseline; internal polymer carrier strategy |
| Thermal environment | 150 C external, 1 hour | 70 C external, 2 hours |
| Thermal result semantics | Cavity-boundary / electronics-zone boundary screening, not chip junction | Inner-shell lower-bound screening, not PCB/cavity/junction/electronics qualification |
| Structural pressure | 10,000 psi historical screening case | ~10 MPa screen, 20 MPa sensitivity, 68.95 MPa historical comparison; design pressure unresolved |

The current work should be read as a change in architecture and evidence basis, not as completion of a finished tool. The large aerogel concept remains historical provenance. The compact architecture is the current preliminary screening direction.

## Verification And Evidence

Evidence inspected for this report:

| Evidence | Use In This Report |
|---|---|
| `results/compact-casing/compact_casing_redesign_report.md` | Current compact architecture, recommended geometry, material hierarchy, structural/thermal language, unresolved items |
| `results/compact-casing/compact_casing_id_od_envelope.csv` | OD/ID, wall, packaging margin, and structural screening table values |
| `results/compact-casing/compact_casing_trade_study.csv` | Architecture comparison, no-aerogel baseline, inner-shell thermal results, total length |
| `cosmo/compact_casing.py` | Constants and generated-evidence semantics for geometry, pressures, electronics envelope, and thermal metric label |
| `tests/test_compact_casing.py` | Verification intent for compact-casing logic and evidence-bound report semantics |
| `results/biweekly-5/biweekly-5.md` | Historical baseline report and figures |
| `results/biweekly-5/summary.json` | Historical geometry, thermal, structural, and limitation values |
| `.agents/context/project.md` | Repository-wide context, evidence hazards, and reporting conventions |
| `.agents/context/biweekly-5/project.md` | Historical Biweekly 5 context and preservation constraints |
| `.agents/tasks/compact-downhole-casing-redesign.md @ ad24d9146815f88368d8f6b1d635831d57aed13d` | Engineering task authority and constraints |
| `.agents/tasks/biweekly-8-report.md @ 833cf553f3b08348670588209655e8e18182ec1c` | Reporting task authority and acceptance criteria |

Accepted compact-casing figures available for review, without duplication in this reporting package:

- `results/compact-casing/figures/compact_cad_assembly.png` - accepted compact CAD assembly render.
- `results/compact-casing/figures/compact_transverse_pcm1808_section.png` - accepted transverse PCM1808 screening section.
- `results/compact-casing/figures/compact_longitudinal_section.png` - accepted compact longitudinal section.
- `results/compact-casing/figures/compact_thermal_trade_study.png` - accepted thermal architecture comparison.

No figures were copied into `results/biweekly-8/`; preserving traceable references avoids duplicating generated evidence.

## Current Engineering Decision

For the current evidence cutoff, the reviewable engineering direction is:

1. Continue with the **44.45 mm / 1.75 in OD**, **3.50 mm wall**, **37.45 mm bore** Inconel 718 shell as the recommended preliminary compact screening configuration.
2. Treat **ID > 30 mm** as a lower-bound direction only; do not treat 30 mm as the target ID.
3. Use the **discrete/conformal polymer carrier** as the internal packaging strategy and keep **aerogel outside the current baseline architecture**.
4. Use **PA66-GF30** as the first physical nylon prototype / validation candidate, while retaining **PEEK** as the engineering benchmark and **PPA** as the secondary higher-performance polyamide candidate.
5. Keep structural and thermal conclusions in screening status until design pressure, physical packaging measurements, thermal path data, material conditioning, and interface details are verified.

This section records the accepted evidence direction; it does not create a new engineering decision.

## Unresolved Items / Risks

- Reporting-period chronology/date range is unresolved; this report uses the exact repository evidence cutoff instead.
- Authoritative casing design pressure is unresolved.
- The ~10 MPa case is only a screening context; 20 MPa is a sensitivity case; 68.95 MPa / 10,000 psi is a historical comparison.
- No pressure qualification, field qualification, manufacturing readiness, or seal qualification is established.
- Actual PCM1808, STM32, power, RTC, SD/storage, analog-front-end, connector, header, solder, wiring, and cable-bend dimensions are unmeasured.
- Electronics power dissipation and representative operating modes remain unresolved.
- The current thermal result does not establish PCB, cavity, junction, or complete electronics temperatures.
- PA66-GF30 hot/wet dimensional response at 70 C, water swelling, well-fluid compatibility, sour-service compatibility, long-duration behavior, and prototype sliding fit remain unresolved.
- PPA procurement and exact carrier validation remain unresolved.
- HTI supplier-controlled datums, thread engagement, seal gland geometry, pressure-retention details, preamplifier mode, pinout, and cable/interface details remain unresolved.

## Next Engineering Work

1. Measure the actual purchased electronics stack: board outlines, thicknesses, headers, connectors, solder protrusions, wiring exits, and cable bend radii.
2. Build and inspect a physical carrier/bore coupon to validate assembly sliding clearance, card-guide fit, and tolerance stack.
3. Run PA66-GF30 dry and wet conditioning checks at representative temperatures, including dimensional change and insertion/extraction force.
4. Confirm authoritative design pressure and pressure-test requirements before using structural screening as a design basis.
5. Extend thermal analysis from the inner shell into the shell/carrier/PCB/electronics path using measured or justified thermal resistances and actual power dissipation.
6. Obtain or confirm supplier-controlled HTI interface data before manufacturing-grade interface drawings.
7. Revisit PPA or PEEK if PA66-GF30 fails dimensional, wet, thermal, compatibility, or assembly validation.

## Evidence / Traceability Table

| Requirement | Report Coverage | Evidence |
|---|---|---|
| REQ-RPT8-001 Evidence-bound report | Report uses accepted repository evidence and labels unresolved chronology | This report; `.agents/tasks/biweekly-8-report.md` |
| REQ-RPT8-002 Current configuration reconciliation | Current dimensions, material hierarchy, and architecture summarized with evidence status | `compact_casing_id_od_envelope.csv`; `compact_casing_trade_study.csv`; `compact_casing_redesign_report.md` |
| REQ-RPT8-003 Strict thermal semantics | Thermal result labeled as inner-shell lower-bound only | `compact_casing_redesign_report.md`; `cosmo/compact_casing.py` thermal metric label |
| REQ-RPT8-004 Strict structural semantics | Structural status remains conditional; pressure cases classified separately | `compact_casing_id_od_envelope.csv`; `compact_casing_redesign_report.md` |
| REQ-RPT8-005 Historical preservation | Historical Biweekly 5 is used only as historical comparison | `results/biweekly-5/`; `.agents/context/biweekly-5/project.md` |
| REQ-RPT8-006 Traceable reporting package | Canonical report generated under `results/biweekly-8/` only | `results/biweekly-8/biweekly-8.md` |

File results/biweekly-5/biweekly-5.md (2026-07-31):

# PERTACOUSTIC: Laporan Biweekly 5

Periode: Biweekly 5

Tanggal: 30 Juli 2026
Status: **Preliminary screening: PASS**

Dokumen ini mencatat desain awal dan pemeriksaan menggunakan perhitungan serta simulasi. Status PASS, jika tercapai, hanya berarti bahwa model awal memenuhi kriteria pemeriksaan yang tertulis di laporan ini. Status tersebut **bukan** gambar manufaktur, sertifikasi bejana tekan, atau kualifikasi seal.

## 1. Rencana dan realisasi pekerjaan

Telah dilakukan desain casing, interface ke HTI-02-DHPC/D, electronics layout, thermal analysis, dan structural analysis.

## 2. Ringkasan kemajuan

- Casing dirancang dengan diameter luar (OD) 200 mm, panjang 425 mm, dinding Inconel 35 mm, tutup depan/belakang 50 mm, aerogel radial 42.5 mm, dan PEEK 2 mm.
- Elektronik dipindahkan menjauh dari kedua tutup. Aerogel aksial di depan sepanjang 50 mm dan di belakang sepanjang 71 mm menghambat panas yang masuk dari ujung casing.
- Model CAD memuat tiga jalur konduktor, bagian analog depan, PCM1808, STM32F411, serta ruang RTC/SD/daya.
- PA12/nylon hanya dipertimbangkan untuk komponen pendukung yang tidak menahan tekanan: dudukan elektronik, pengarah kabel, pengganjal, atau penahan tarikan kabel. PA12/nylon tidak dipakai sebagai penghalang langsung terhadap fluida sumur.

## 3. Dasar desain dan istilah mekanik

Ukuran nominal ulir yang dipakai adalah `7/16-20 UNF-2A` pada casing untuk dipasangkan dengan `7/16-20 UNF-2B` pada HTI. Nominal berarti nama ukuran menurut standar; ukuran hasil manufaktur tetap dapat sedikit lebih besar atau kecil selama masih berada dalam toleransi yang diizinkan. `7/16` adalah diameter utama nominal, `20` berarti 20 ulir per inci, `UNF` adalah seri ulir halus, `2A` adalah kelas ulir luar, dan `2B` adalah kelas ulir dalam.

**Thread/ulir** adalah alur heliks untuk menyambungkan dua komponen. **Thread HTI** berarti ulir sambungan milik hydrophone HTI, bukan seal tekanan untuk ruang elektronik. Gambar HTI masih bertanda “for reference only”. Karena itu, **datum** (acuan pengukuran)—permukaan atau sumbu acuan untuk semua pengukuran—dan **thread tolerance** (toleransi ulir)—batas penyimpangan diameter, pitch, serta bentuk ulir—harus dikonfirmasi kepada HTI sebelum manufaktur.

**Envelope** adalah kotak atau ruang batas yang disediakan agar suatu komponen pasti muat. Envelope sementara STM32F411 adalah 55 × 22 × 12 mm dan PCM1808 adalah 52 × 32 × 18 mm. **Assembly clearance** 1,5 mm adalah ruang tambahan agar board dapat dimasukkan dan tidak bergesekan. Dari ukuran tersebut digunakan **clear ID** 41 mm, yaitu diameter dalam bersih yang benar-benar tersedia untuk elektronik setelah material casing dan insulasi dihitung. Visualisasi model CAD rakitan casing ditunjukkan pada **Gambar 1**.

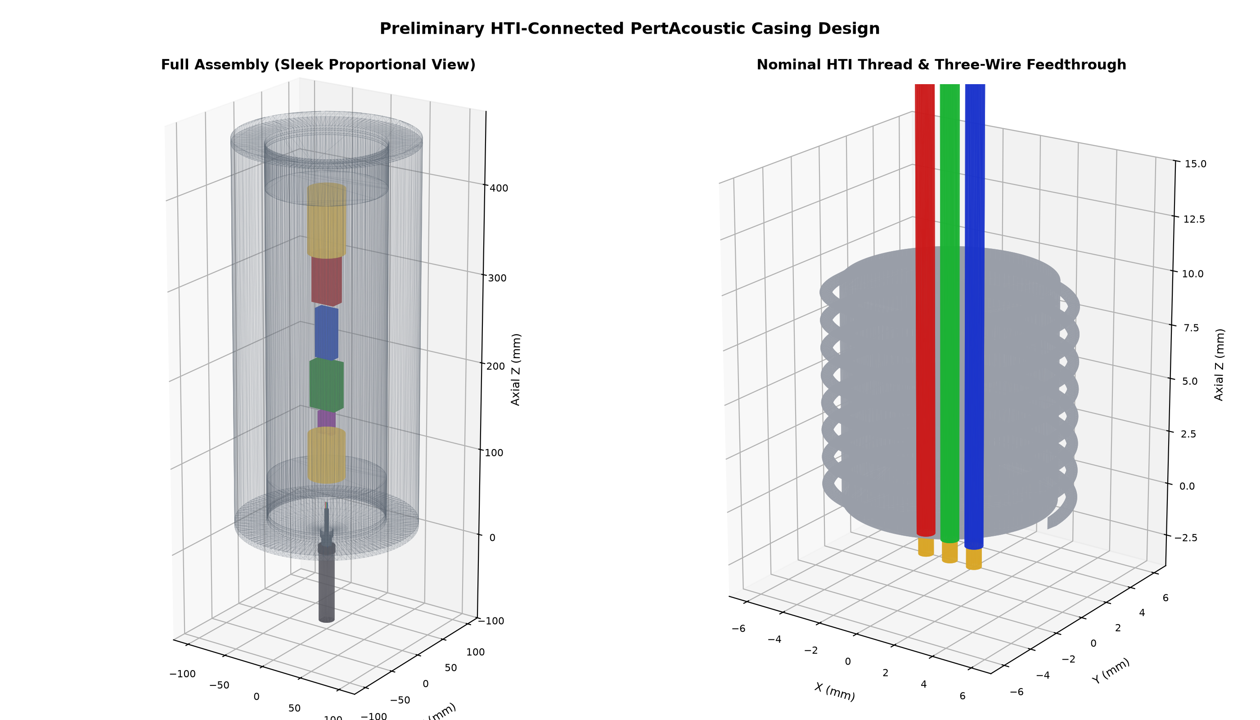
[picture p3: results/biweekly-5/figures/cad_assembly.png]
Rakitan CAD

**Gambar 1: Model CAD rakitan casing PertAcoustic 3D.**

Adapter depan terdiri dari ulir nominal, **shoulder** atau bidang bertingkat yang menjadi penahan aksial, **spigot** atau bagian silinder yang masuk ke bore pasangan untuk menjaga posisi, tiga lubang kabel, dan dua alur seal awal. **Seal groove** adalah alur tempat O-ring atau seal. **Pressure seal** adalah komponen yang mencegah fluida bertekanan masuk ke ruang elektronik; lokasinya terpisah dari ulir HTI.

Jenis **elastomer** atau bahan lentur seal, **backup ring** yang menopang seal agar tidak terdorong keluar, **extrusion gap** atau celah tempat seal dapat tertekan keluar, dan **tolerance stack** atau gabungan seluruh variasi ukuran komponen belum ditetapkan. Karena itu, geometri alur yang terlihat di CAD masih konseptual dan belum boleh dibuat.

Dalam model struktur, **barrel** adalah dinding silinder panjang dan **endcap** adalah tutup tekanan di depan serta belakang. Model FEA (Finite Element Analysis) dibuat **defeatured**, artinya detail kecil seperti ulir, kontak seal, dan alur lokal dihilangkan agar pemeriksaan global casing lebih stabil dan lebih cepat.

## 4. Susunan elektronik

Urutan aksial komponen di dalam casing dapat dilihat pada penampang memanjang (**Gambar 2**). Urutan aksialnya adalah HTI, analog front-end, PCM1808, STM32F411, lalu RTC/SD/daya. **Conductor path** adalah jalur listrik dari tiga pin/kabel HTI menuju elektronik. Tiga jalur dipertahankan karena pinout final belum dikonfirmasi.

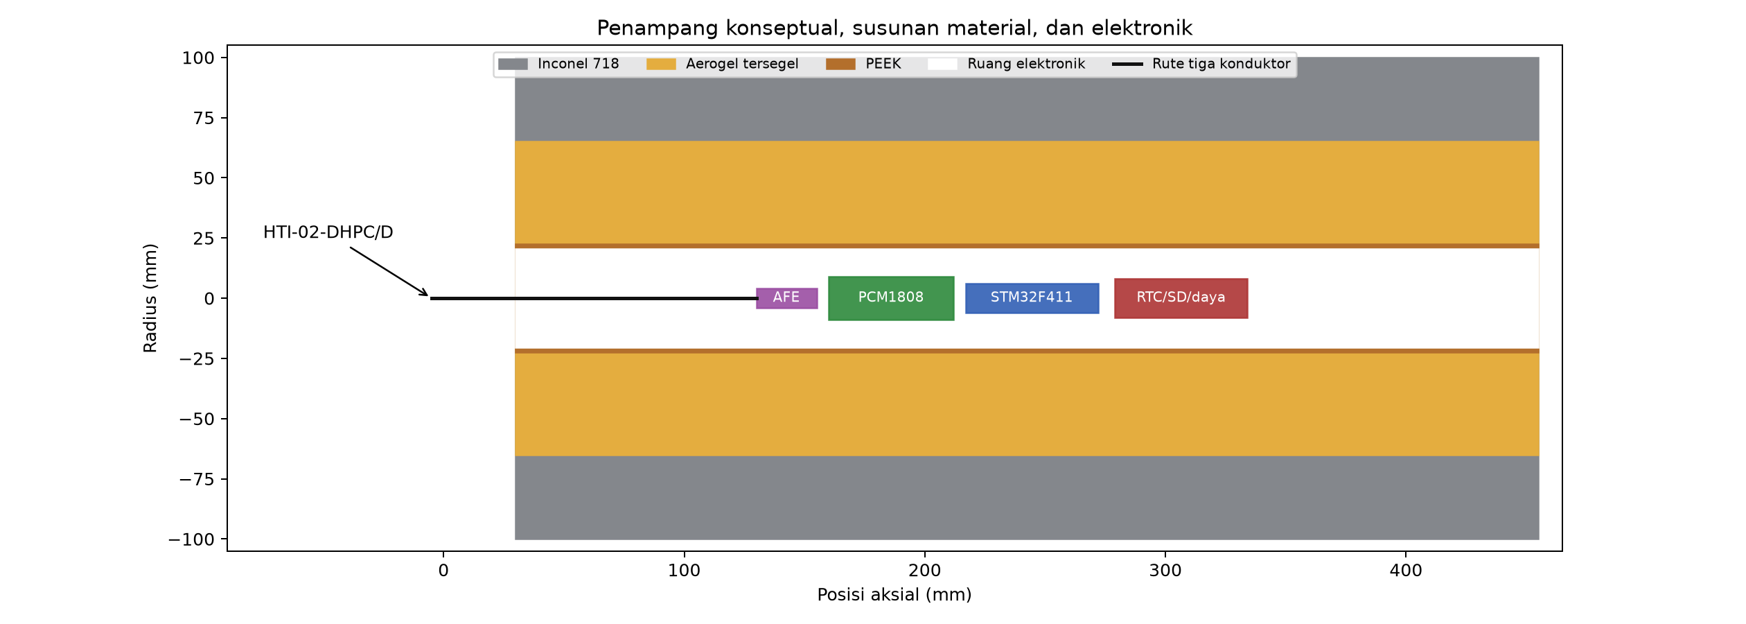
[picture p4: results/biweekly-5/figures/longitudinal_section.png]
Penampang memanjang

**Gambar 2: Penampang memanjang susunan ruang elektronik dan insulasi aksial.**

**Analog front-end** adalah rangkaian pertama yang menerima sinyal analog kecil dari hydrophone, kemudian menguatkan dan menyaringnya sebelum masuk ke PCM1808. **Analog front-end zone** adalah ruang di dalam model yang dialokasikan untuk rangkaian tersebut. **Configurable analog front-end** berarti nilai penguatan, penyaringan, dan hubungan pin belum dikunci sehingga dapat disesuaikan setelah data HTI tersedia.

**Preamplifier mode** menjelaskan apakah preamplifier berada di dalam HTI, membutuhkan catu daya tertentu, dan bagaimana sinyal keluarannya dibaca. **Pinout** adalah daftar fungsi setiap pin, misalnya sinyal, ground, dan catu daya. PCM1808 mengubah sinyal analog menjadi data digital; STM32F411 mengendalikan akuisisi dan penyimpanan; ruang RTC/SD/daya disediakan untuk jam waktu nyata, kartu penyimpanan, dan rangkaian catu daya.

## 5. Pemeriksaan struktur

Hasil screening geometri dan ketersediaan ruang radial untuk beberapa opsi OD dirangkum pada **Tabel 1**.

**Tabel 1: Hasil screening ketersediaan ruang radial dan dimensi casing untuk berbagai variasi diameter luar (OD).**

| OD (mm) | Muat | Dinding Inconel (mm) | Aerogel (mm) | Pemeriksaan analitis | Catatan |
|---:|---|---:|---:|---|---|
| 43 | no | - | - | - | Insufficient radial space for 41 mm clear ID, PEEK, pressure wall, and aerogel. |
| 50 | no | - | - | - | Insufficient radial space for 41 mm clear ID, PEEK, pressure wall, and aerogel. |
| 60 | yes | 5.25 | 2.25 | PASS | analytical geometry/wall screen only |
| 200 | yes | 35.0 | 42.5 | PASS | analytical geometry/wall screen only |

Perhitungan **Lamé** memperkirakan tegangan pada dinding silinder tebal akibat tekanan. **Equivalent stress** atau tegangan von Mises menyederhanakan kombinasi tegangan menjadi satu angka untuk dibandingkan dengan kekuatan luluh material. Hasil analitis dinding adalah 206.79 MPa dengan **factor of safety (FoS)** 4.84. FoS adalah perbandingan kekuatan material terhadap beban terhitung; FoS 2 berarti kapasitas perhitungan dua kali beban rencana.

Hasil distribusi tegangan dan deformasi dari analisis elemen hingga (FEA) ditunjukkan pada **Gambar 3**. FEA menghitung seluruh barrel dan kedua endcap. Tegangan coarse, medium, dan fine adalah 199.21, 206.52, dan 212.51 MPa. **Displacement** adalah perpindahan bentuk akibat beban; hasil fine adalah 0.785 mm.

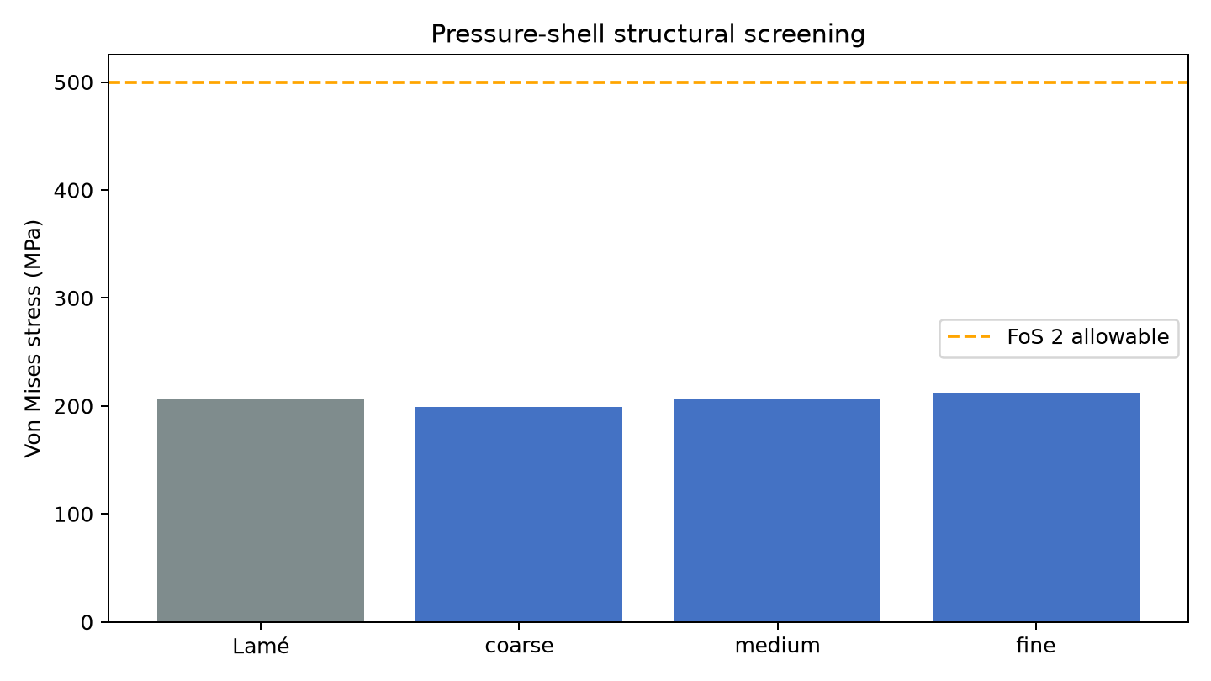
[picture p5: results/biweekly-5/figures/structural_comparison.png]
Perbandingan struktur

**Gambar 3: Perbandingan hasil simulasi struktur FEA casing pada variasi mesh.**

**Mesh convergence** memeriksa apakah hasil berubah ketika elemen dibuat lebih kecil. Perubahan medium ke fine adalah 2.82% untuk tegangan dan 3.47% untuk displacement. Angka ini dilaporkan sebagai informasi karena pemeriksaan struktur periode ini dibatasi pada screening awal, bukan sertifikasi struktur.

**Buckling** adalah kegagalan ketika dinding tertekuk akibat tekanan luar sebelum material patah. Persamaan silinder panjang memberi buckling factor analitis 18.04; faktor 2 berarti kapasitas hitung sedikitnya dua kali tekanan rencana. Pemeriksaan ini cukup untuk screening awal, tetapi bukan pengganti uji tekanan atau sertifikasi. Perhitungan retensi ulir memberi FoS 6.58, tetapi angka nominal ini belum menggantikan konfirmasi toleransi ulir dan desain seal.

**Thermo-mechanical load** berarti beban struktur yang menggabungkan tekanan dan perubahan temperatur. Model sekarang masih memindahkan profil temperatur radial ke model struktur, belum melakukan **direct mapping** dari setiap titik hasil termal 3D. Hasil struktur karena itu tetap dibaca sebagai screening awal.

## 6. Pemeriksaan termal

Riwayat perubahan temperatur pada tiap zona elektronik selama 1 jam operasi ditunjukkan pada **Gambar 4**. Simulasi termal 3D casing tertutup memperhitungkan barrel, endcap Inconel depan/belakang, aerogel radial, **front/rear axial aerogel buffer**, serta daya panas internal elektronik sebesar **1 W** (1 joule per detik). **Axial aerogel buffer** adalah lapisan aerogel memanjang di antara endcap dan ruang elektronik untuk menghambat aliran panas aksial dari ujung casing.

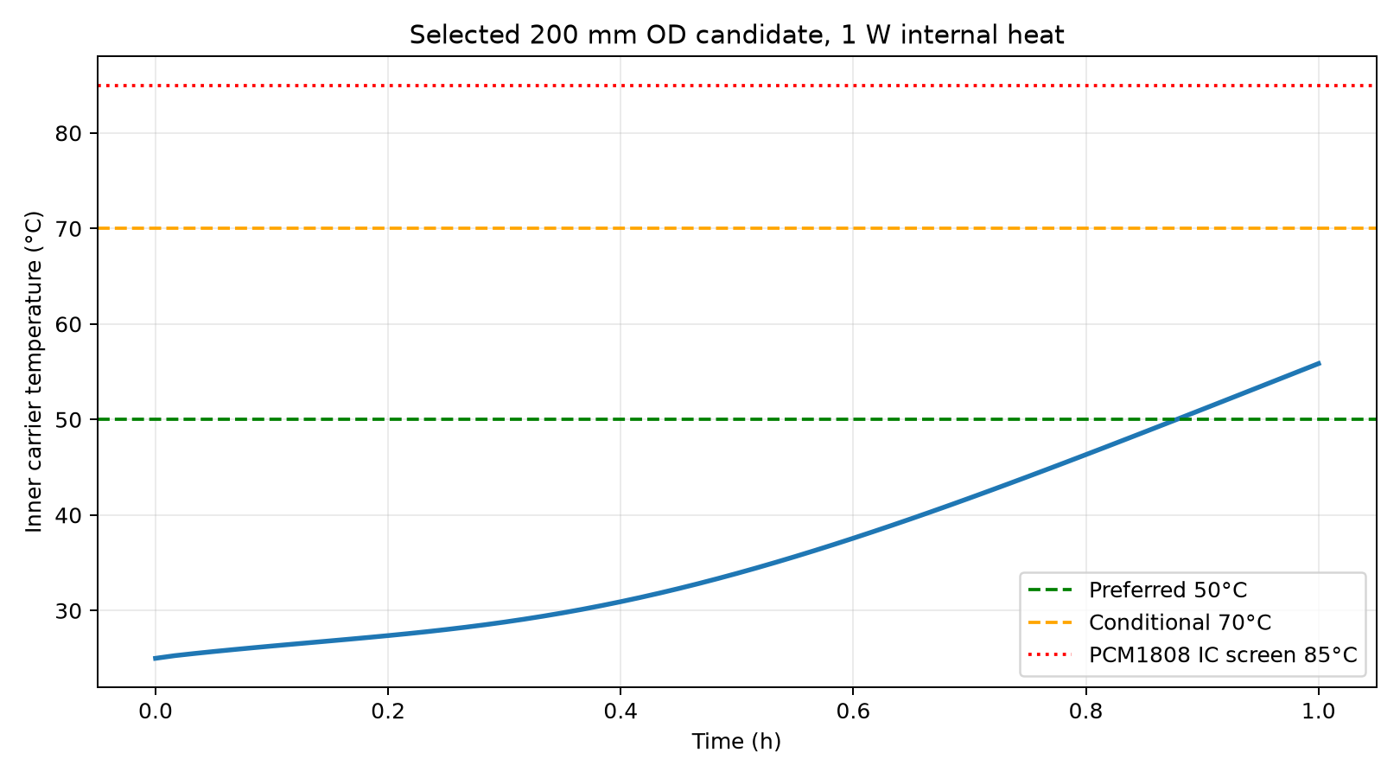
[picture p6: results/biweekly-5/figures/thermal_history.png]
Riwayat temperatur

**Gambar 4: Profil riwayat temperatur transient zona elektronik selama simulasi 1 jam.**

Parameter masukan dan kondisi batas yang digunakan dalam simulasi termal dirangkum pada **Tabel 2**.

**Tabel 2: Parameter input dan kondisi batas simulasi model termal 3D.**

| Pemeriksaan input model | Nilai |
|---|---|
| Temperatur awal | 25°C |
| Batas luar | 150°C pada barrel dan kedua endcap |
| Panas internal | 1 W total |
| Waktu | 3.600 detik atau 1 jam |
| Perubahan mesh medium ke fine | 1.1799% |

Hasil perhitungan temperatur maksimum pada permukaan dalam (batas rongga) tiap zona elektronik dirangkum pada **Tabel 3**.

**Tabel 3: Temperatur maksimum pada batas rongga tiap zona elektronik setelah simulasi 1 jam.**

| Zona elektronik | Temperatur maksimum batas rongga setelah 1 jam (°C) | Penilaian |
|---|---:|---|
| Analog front-end | 62.06 | diterima sementara |
| PCM1808 | 62.88 | diterima sementara |
| STM32F411 | 62.38 | diterima sementara |
| RTC/SD/power | 62.31 | diterima sementara |

**Maximum cavity-boundary temperature** adalah temperatur tertinggi pada permukaan dalam yang menghadap ruang elektronik, bukan temperatur chip. Nilai maksimum model adalah 62.88°C. **Chip junction temperature** adalah temperatur di bagian aktif silikon; nilainya belum dihitung karena board dan chip belum dimodelkan sebagai benda padat.

**Operating ceiling** adalah temperatur operasi maksimum yang diizinkan produsen komponen. PCM1808 memiliki ceiling 85°C [2], tetapi desain memakai batas pemeriksaan 70°C agar tersedia margin.

Perbedaan model radial dan model 3D tertutup berasal dari panas yang juga masuk melalui endcap. Menambah diameter dan aerogel radial memperlambat panas dari sisi barrel, tetapi tidak memperpanjang jalur panas dari depan atau belakang. Karena itu, desain ini juga memindahkan elektronik dan menambah insulasi aksial. Studi trade-off respon termal radial terhadap variasi diameter dan ketebalan insulasi ditunjukkan pada **Gambar 5**.

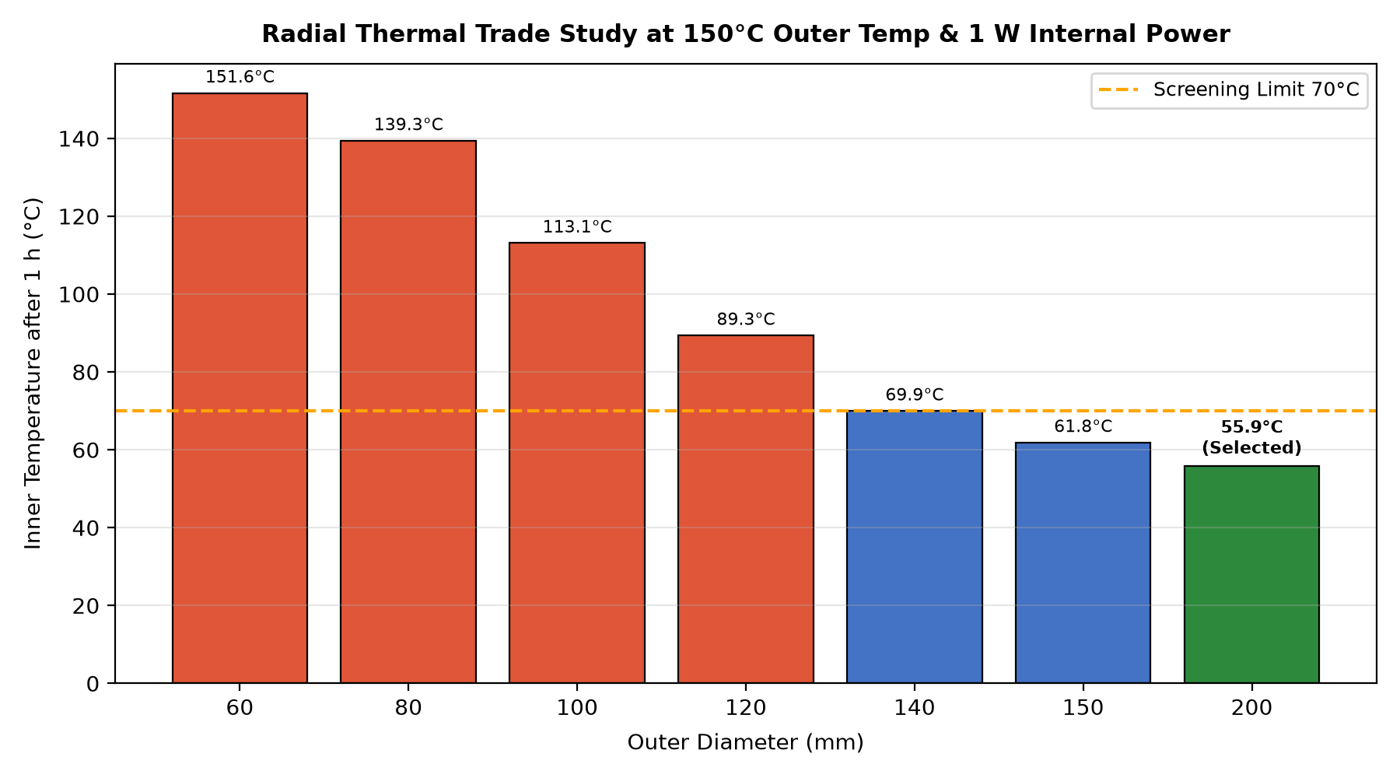
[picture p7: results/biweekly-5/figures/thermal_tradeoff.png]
Studi trade-off termal radial

**Gambar 5: Studi trade-off termal radial terhadap variasi diameter luar (OD) dan insulasi aerogel.**

**Thermal resistance** dalam K/W menyatakan kenaikan beda temperatur yang dibutuhkan untuk mengalirkan satu watt panas; angka lebih besar berarti insulasi lebih baik. Perkiraan resistansi aksial depan adalah 454.4 K/W dan belakang 645.2 K/W. **Axial heat leak** adalah panas yang merambat dari endcap menuju elektronik melalui jalur tersebut; perkiraan awalnya 0.28 W dari depan dan 0.19 W dari belakang.

Angka **0,0007%** pada model lama berarti hasil mesh medium dan fine hanya berbeda sekitar tujuh bagian per sejuta. Itu menunjukkan hasil mesh termal lama sudah stabil, tetapi tidak berarti temperaturnya memenuhi batas. Nilai desain baru yang dipakai untuk status adalah 1.1799%.

## 7. Hasil saat ini

Status desain: **Preliminary screening: PASS**.

Status PASS ditetapkan apabila seluruh zona elektronik tidak melebihi 70°C, perubahan mesh termal di bawah 5%, tegangan statik fine tidak melebihi 500 MPa, serta perhitungan analitis memberi FoS luluh dan buckling factor sedikitnya 2. Status ini tetap merupakan screening awal, bukan sertifikasi struktur.

## 8. Pekerjaan berikutnya

### Dapat dilakukan sekarang dengan model

- Menjaga CAD, posisi elektronik, panjang insulasi, dan geometri endcap tetap konsisten dengan model yang sudah diperiksa.
- Mengulang simulasi bila ukuran, daya, material, tekanan, atau temperatur rencana berubah.
- Membuat daftar pendek material berdasarkan produk yang benar-benar tersedia.

### Memerlukan pengukuran, data pemasok, atau pengujian fisik

- Mengukur board STM32F411 dan PCM1808 beserta konektor dan header.
- Mengukur daya elektronik saat logging dan standby; angka 1 W saat ini masih asumsi.
- Memilih grade aerogel, PEEK, perlakuan panas Inconel, elastomer, dan backup ring yang dapat dibeli.
- Menghitung alur seal dan tolerance stack setelah material seal, celah, serta ukuran manufaktur ditetapkan.
- Menguji kupon Inconel/aerogel/PEEK di oven atau bak panas untuk membandingkan model dengan benda nyata.

## 9. Referensi

1. [High Tech Inc., HTI-02-DHPC/D](https://www.hightechincusa.com/products/hydrophones/hti02dhpc.html)
2. [Texas Instruments, PCM1808](https://www.ti.com/product/PCM1808)
3. [Special Metals, INCONEL Alloy 718 Technical Bulletin](https://www.specialmetals.com/documents/technical-bulletins/inconel/inconel-alloy-718.pdf)
4. [Victrex, PEEK 450G Technical Data Sheet](https://images.victrex.com/-/media/downloads/datasheets/victrex_tds_450g.pdf)
5. [Aspen Aerogels, Pyrogel HPS Product Data Sheet](https://www.aerogel.com/wp-content/uploads/2021/06/Pyrogel-HPS-Datasheet-English.pdf)
6. HTI-02-DHPC/D Mechanical Outline 02-001-25-00-00, supplier document marked "for reference only".

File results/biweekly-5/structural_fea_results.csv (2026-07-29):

mesh | pressure_faces | status | max_displacement_mm | max_nodal_von_mises_MPa | analytical_buckling_factor
coarse | 7856 | passed | 0.7759115174457716 | 199.20685952573686 | 18.0447320258145
medium | 13794 | passed | 0.7575062874590548 | 206.5233174438688 | 18.0447320258145
fine | 25738 | passed | 0.7847184828650337 | 212.5130842571111 | 18.0447320258145

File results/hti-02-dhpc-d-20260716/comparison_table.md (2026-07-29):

# Transient Thermal Results

Pass threshold: 50.00 C.

| Iteration | Configuration | OD (mm) | Length (mm) | Max Temp (C) | Status |
|:---|:---|:---|:---|:---|:---|
| iteration_01 | SS316 + Aerogel + PEEK | 43.0 | 100.0 | 25.02 | PASS |

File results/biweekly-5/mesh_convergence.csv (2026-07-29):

od_mm | coarse_C | medium_C | fine_C | medium_to_fine_pct
60.0 | 151.60071374588648 | 151.60074071419126 | 151.6007474484623 | 4.4421093911599885e-06
65.0 | 152.01213651686666 | 152.01200116051612 | 152.01196781740418 | 2.1934530824117606e-05
70.0 | 149.88876716677368 | 149.89029717479121 | 149.89067954380798 | 0.0002550985944729053
80.0 | 139.29345305959598 | 139.3323312110486 | 139.34200609575208 | 0.0069432649741224955
100.0 | 112.77655114414281 | 113.02331333185911 | 113.08490066684348 | 0.05446114788198613
120.0 | 88.75700027991421 | 89.21856875709302 | 89.3354904986448 | 0.13087938611984393
140.0 | 69.33016100460785 | 69.80805295901948 | 69.93446399475191 | 0.1807564232449362
146.0 | 64.46219656378305 | 64.89010621863835 | 65.00616931063564 | 0.1785416572428322
150.0 | 61.34721614852664 | 61.72629829081836 | 61.83162403217929 | 0.17034283509375986
200.0 | 55.526545839072845 | 55.779967647034056 | 55.85592820214571 | 0.1359937209113256

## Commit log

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2026-06-20 docs: create COSMO-Agent CAD-CAE orchestration skill and update session log
2026-06-22 Add new files for Biweekly 2 (E-EOR and PertAcoustic timeline)
    [Timeline Pekerjaan PertAcoustic (Vacant).xlsx]
2026-06-22 docs: add comprehensive sensor market survey and TCO analysis
2026-06-23 feat: test queck poc
    [casing_iter1.step, casing_iter2.step]
2026-06-23 feat: add simulation results, node validation, and automated optimization scripts for COSMO iterations
    [casing_iter1.step, casing_iter2.step, numerical_data.csv]
2026-06-23 feat: implement casing iteration and add automated optimization scripts for structural analysis
    [casing_iter1.step, casing_iter2.step, numerical_data.csv]
2026-06-23 feat: automate optimization workflow and add casing iteration 2 results
    [casing_iter1.step, casing_iter2.step, numerical_data.csv]
2026-06-23 feat: add transient thermal simulation results, CAD casing models, and analysis scripts for project iteration comparison
    [casing_iter1.step, casing_iter2.step, numerical_data.csv]
2026-06-23 feat: implement automated optimization workflow and generate simulation iteration data
    [casing_iter1.step, casing_iter3.step, casing_iter4.step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]
2026-06-23 refactor: transition to dual-zone architecture and specify HPHT sensor requirements for 150°C/14,500 psi operation
2026-06-24 feat: add temperature visualization script and reference technical documentation
2026-06-24 feat: add cad generator, material library, and solver interface modules for cosmogenic thermal simulations
    [casing_iter1.step, casing_iter2.step, casing_iter3.step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]
2026-06-24 docs: add Mermaid flowchart representing the COSMO agent workflow
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2026-06-27 docs: add presentation slide outline and workflow flowchart for agentic loop design methodology
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2026-06-27 Add COSMO thermal optimization results, plots, and runner scripts
    [casing_iter1.step, casing_iter2.step, casing_iter3.step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]
2026-07-16 Add new skills for agent-based task management and optimization
    - Introduced `delegate-work` skill for managing independent tasks and delegation processes.
    - Added `develop-feature` skill to facilitate feature requests, planning, and implementation.
    - Created `find-agent-skills` skill for discovering and validating external agent skills.
    - Implemented `fix-bug` skill for diagnosing and fixing reported issues with regression coverage.
    - Developed `generate-readme` skill for creating project README sources without altering the root README.
    - Added `onboard-repository` skill for documenting repository behavior and initializing project context.
    - Introduced `project-handoff` skill for saving and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
    [Timeline Pekerjaan PertAcoustic (Vacant).xlsx]
2026-07-16 Remove unused Excel file: Timeline Pekerjaan PertAcoustic (Vacant).xlsx
    [Timeline Pekerjaan PertAcoustic (Vacant).xlsx]
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2026-07-16 feat: restructure project layout and add core simulation and hydrophone modeling utilities
    [casing_iter1.step, casing_iter2.step, casing_iter3.step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]
2026-07-16 feat: generate results and analysis for iteration 1 optimization
    [numerical_data.csv]
2026-07-29 Add Biweekly 5 project context and results compiler tests
    - Created a new project context file for Biweekly 5, outlining the scope, execution guardrails, and decisions needed before design and report execution.
    - Introduced a unit test for the results compiler to ensure it correctly handles run thresholds without inventing metrics, validating output against expected results.
    [numerical_data.csv]
2026-07-29 Add biweekly-5 results and tests
    - Created input_spec.json with preliminary engineering data.
    - Added mesh convergence data in mesh_convergence.csv.
    - Included structural FEA results in structural_fea_results.csv.
    - Compiled summary of results in summary.json.
    - Documented thermal results in thermal_results.csv.
    - Implemented unit tests for geometry, thermal model, and thread retention in test_biweekly5.py.
    [hti_casing_analysis.step, hti_casing_detailed.step, mesh_convergence.csv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]
2026-07-29 Update biweekly-5 results and specifications
    - Modified input_spec.json to reflect new status and updated material properties.
    - Adjusted selected geometry parameters including outer diameter and wall thickness.
    - Updated thermal_results.csv with new temperature data for various configurations.
    - Enhanced structural_fea_results.csv to include buckling factors and statuses.
    - Revised summary.json to include detailed results from thermal and structural simulations.
    - Updated mesh_convergence.csv with new convergence data.
    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
    [hti_casing_analysis.step, hti_casing_detailed.step, mesh_convergence.csv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]
2026-07-29 Refactor biweekly 5 report and CAD files; update thermal and structural analysis
    - Revised the biweekly 5 report for clarity and structure, including updates to the design status and progress summaries.
    - Enhanced CAD files with updated timestamps and color specifications for better visualization.
    - Improved summary JSON to include detailed component maximum temperatures and axial heat leak metrics.
    - Added unit tests for component temperature zones and axial heat leak calculations to ensure accuracy and reliability.
    [hti_casing_analysis.step, hti_casing_detailed.step]
2026-07-29 Update biweekly-5 results and revise geometry parameters
    - Changed status from preliminary_fail to preliminary_pass in input_spec.json.
    - Updated derived_OD_mm values and selected_geometry parameters to reflect new design.
    - Revised thermal and structural results in mesh_convergence.csv and structural_fea_results.csv.
    - Updated thermal_results.csv with new temperature data for revised geometry.
    - Modified summary.json to reflect changes in engineering status and thermal calculations.
    - Enhanced test_biweekly5.py to validate new geometry and ensure consistency in engineering status.
    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
    [hti_casing_analysis.step, hti_casing_detailed.step, mesh_convergence.csv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]
2026-07-29 docs: add biweekly 5 report, CAD assembly, and supporting technical analysis code
    [hti_casing_detailed.step]
2026-08-26 refactor: consolidate agent framework by migrating to root Codex instructions and removing legacy role/skill definitions
2026-08-26 feat: implement compact downhole casing design study including structural, thermal, and CAD modeling tools
    [compact_casing_trade_study.csv]
2026-08-26 refactor: transition compact casing architecture to aerogel-free design and update thermal/packaging validation logic
    [compact_casing_trade_study.csv]
2026-08-26 fix: refine aerogel-free compact casing architecture
    [compact_casing_trade_study.csv]
2026-08-26 fix: resolve compact casing carrier interference
    [compact_casing_trade_study.csv]
2026-08-26 fix: harden compact casing carrier verification
    [compact_casing_trade_study.csv]
2026-08-26 fix: finalize compact casing screening evidence
    [compact_casing_trade_study.csv]
2026-08-26 fix: finalize compact casing thermal screening semantics
    [compact_casing_trade_study.csv]
2026-08-26 feat: evaluate PA66-GF30 compact casing carrier
    [compact_casing_trade_study.csv]
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2026-09-01 fix: close nylon prototype screening evidence gaps
2026-09-01 fix: close nylon prototype test and evidence gaps
2026-09-01 fix: finalize nylon prototype verification artifacts
    [compact_casing_trade_study.csv]
2026-09-02 feat: add practical id od prototype envelope
    [compact_casing_id_od_envelope.csv]
2026-09-02 fix: make id od recommendation evidence-driven
    [compact_casing_id_od_envelope.csv]
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
